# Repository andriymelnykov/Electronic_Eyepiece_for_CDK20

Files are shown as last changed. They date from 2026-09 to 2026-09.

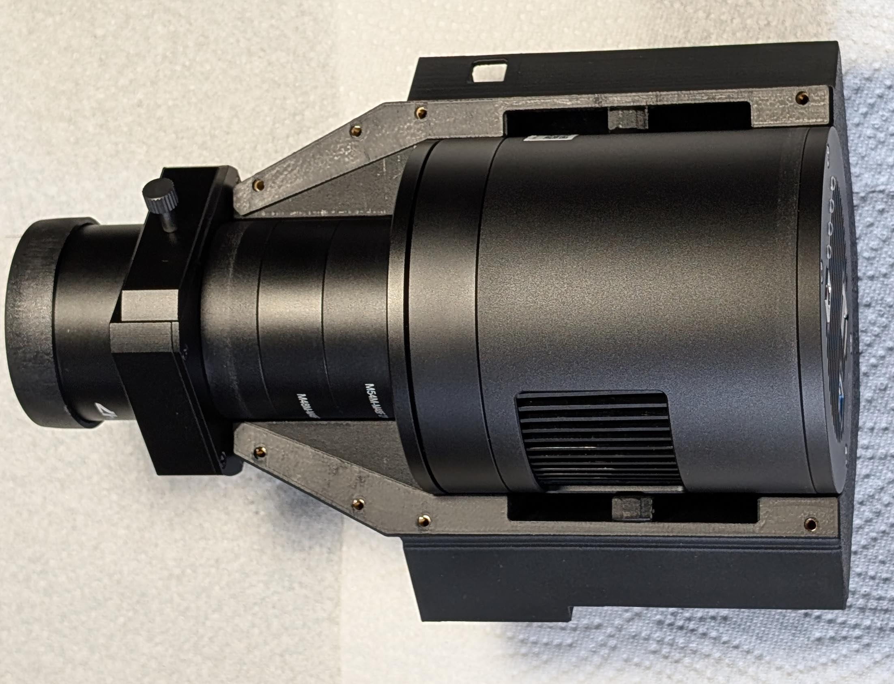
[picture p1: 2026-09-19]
Assembly/19_Assembly.jpg

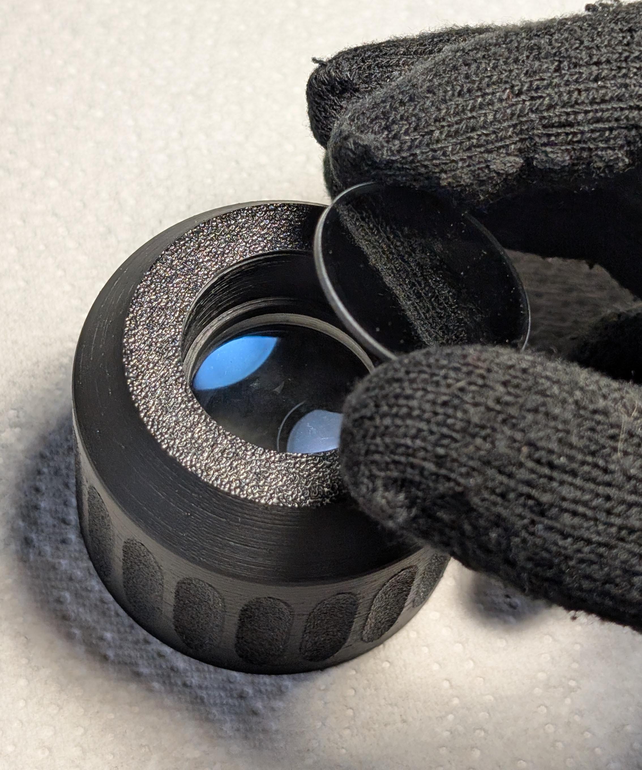
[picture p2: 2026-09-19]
Assembly/05_Assembly.jpg

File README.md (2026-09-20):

# Electronic_Eyepiece_for_CDK20
Electronic eyepiece for CDK20 telescope (or almost any 2-inch focuser)

This is my third creation of electronic eyepiece system for observing deep-sky objects.

The device was custom-developed and built for the Robert-Mayer-Sternwarte astronomy club in Heilbronn, Germany, with the main goal: to preserve the feeling of looking through a real telescope while making faint deep-sky objects such as galaxies and nebulae visible in color — even from the middle of the city.

The system combines the enormous light-gathering power of a 50 cm CDK20 telescope, a modern full-frame astronomy camera with an optical reducer, and electronic eyepiece display. Image processing is performed on an external PC using own custom-written, highly optimized, ultra-fast EAA (Electronically Assisted Astronomy) software.

Thanks to this combination, most objects begin to appear in the eyepiece almost immediately and develop into a detailed color image within well under a minute of live stacking.

The electronic eyepiece creates a very different observing experience compared with looking at a normal computer screen. The image is presented optically at infinity, similar to a conventional telescope eyepiece, so the object appears large, distant, and suspended in space. It gives the impression of actually looking into the telescope rather than watching an image on a monitor.

Although this version was designed specifically for our CDK20, the electronic eyepiece itself should work with many telescopes equipped with a 2-inch focuser and sufficient image-circle coverage for a full-frame sensor.

See it in action: https://youtu.be/fDfaFu6sCa4

See discussion here: https://www.cloudynights.com/forums/topic/1010946-my-third-eaa-setup-with-diy-electronic-eyepiece-for-local-astroclub

-------------------------
Software used on PC for image processing is my other project:
https://github.com/andriymelnykov/Digital_Eyepiece_APP

Config files are provided as used on our CDK20 telescope and are examples.
Proper dark frames and flat frames calibration and eventually fine tuning of parameters needed for each device and telescope combination.
Calibration frames must be updated periodically (capture with third party SW).
The relative position of optical unit to telescope should be maintained for proper flat correction (see alignment marks in user manual).

User manual is an example.

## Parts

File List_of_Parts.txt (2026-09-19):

1. Camera: ToupTek SkyEye24AC.
https://www.touptek-astro.com/dso-cooled-cameras/SkyEye24AC/

2. ToupTek M54M-M48F 21mm and M48M-M48F 16.5mm Extension Tubes from SkyEye24AC Package Contents.

3. TS-Optics TSVF215 M48M-M48F 15mm Extension Tube.
https://www.teleskop-express.de/de/adapter-10/adapter-verlaengerung-124/ts-optics-15mm-verlaengerung-mit-m48-2-filtergewinde-und-2-durchmesser-1651
Alternatively any M48M-M48F 15mm Extension Tube with outer diameter of 50.8 mm (2 inches).

4. TS-Optics TSFSLM48 M48 Filter Changer - strengthened Design.
https://www.teleskop-express.de/en/filters-254/filter-wheels-and-filterslider-120/ts-optics-m48-filter-changer-strengthened-design-10475
Plus filter holders, 3x in total.
Alternatively any M48M-M48F 2-inch filter holder with thickness of 16-18mm.

5. Optolong UV/IR Blocking Filter and Luminance Filter 2" mounted.
https://www.teleskop-express.de/en/filters-254/photo-r-g-b-and-ir-cut-filters-267/optolong-uv-ir-blocking-filter-and-luminance-filter-2-mounted-11845

6. Optolong 2" L-eNhance Nebula Filter.
https://www.teleskop-express.de/en/filters-254/photo-swanband-nebular-filters-304/photo-narrowband-filters-2-inch-m48-302/optolong-2-l-enhance-nebula-filter-for-dslr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

7. Baader 2" UHC-L Ultra-L-Booster Nebula Filter.
https://www.teleskop-express.de/en/filters-254/nebular-filters-for-visual-observing-88/baader-2-uhc-l-ultra-l-booster-nebula-filter-for-astrophotography-16364

8. TS-Optics CCD47 2" CCD Reducer 0.67x.
https://www.teleskop-express.de/en/astrophotography-and-photography-15/imaging-correctors-for-telescopes-138/ts-optics-2-ccd-reducer-0-67x-for-rc-flatfield-telescope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
Alternatively Astro Physics CCDT67 0.67x Focal Reducer should be ok, but not tested.

9. 2x compression springs 35mm x 9mm x 0.7mm from common spring set.
Depending on your preferences other springs may be needed.

10. Wisecoco 2.9 Inch 2K TFT LCD Display 2160x2160 LS029B3SX06 with HDMI control board.
https://de.aliexpress.com/item/1005008080918162.html

11. Fischerelektronik USB 2 B 180 - USB 2.0 Typ B connector receptacle.
https://www.reichelt.de/de/de/shop/produkt/usb_2_0_typ_b_buchse-304025
Or similar with same dimensions.

12. CHERRY MX1B-52NA Low profile RGB speed switch for keyboards.
https://www.reichelt.de/de/de/shop/produkt/cherry_mx_low_profile_silver_rgb_speed_-_tastenmodul-281332

13. Arduino Pro-Micro, ATMega32U4, 5V / 16 MHz.
https://www.reichelt.de/de/de/shop/produkt/arduino_kompatibles_micro_pro_board_atmega32u4_microusb-330660

14. RGB strip with 7x WS2812 LEDs.

15. Short microUSB cable.

16. 2x 561.OA61 OptiMedia Achromat OA61, Ø 31 mm, f = 135.5 mm.
https://astromedia.de/OptiMedia-Achromat-OA61
Alternatively achromats with same data.

17. Grey ND8 filter size 37mm.
https://www.ebay.de/itm/324441899850?var=513510410016
Glass diameter 33.0-33.2 mm.

18. Thick silicone grease.

19. Screws M3x8 - 3x

20. Screws M3x10 - 19x

21. Screws M3x16 - 6x

22. Screws M2.5x12 - 4x

23. Black 3d-printing filament.

24. Transparent 3d-printing filament.

25. M3 inserts for 3d-printing - 10x

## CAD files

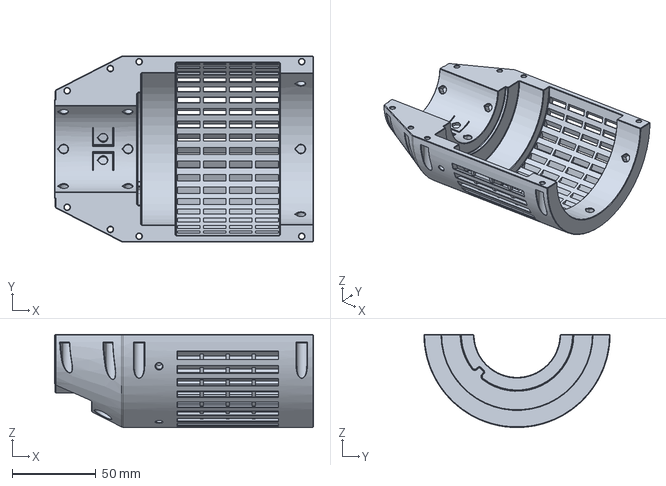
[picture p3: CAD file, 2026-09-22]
3D_Models/Case_Bottom.step
154.3 x 111.0 x 55.5 mm

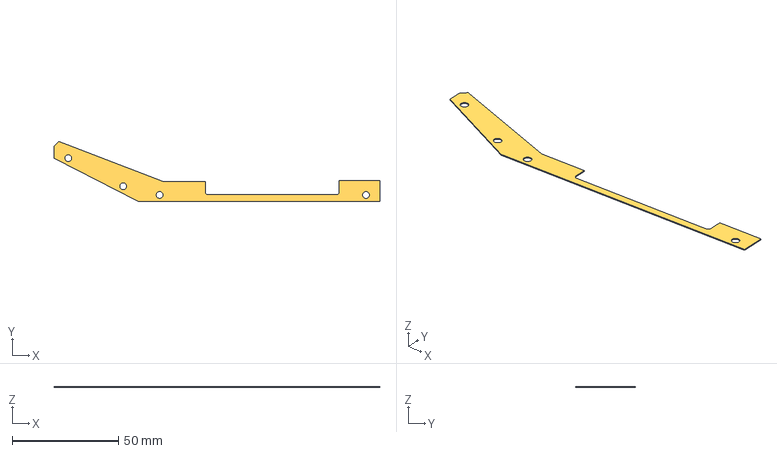
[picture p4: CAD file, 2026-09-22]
3D_Models/Gasket_Pad.step
153.1 x 28.2 x 0.4 mm

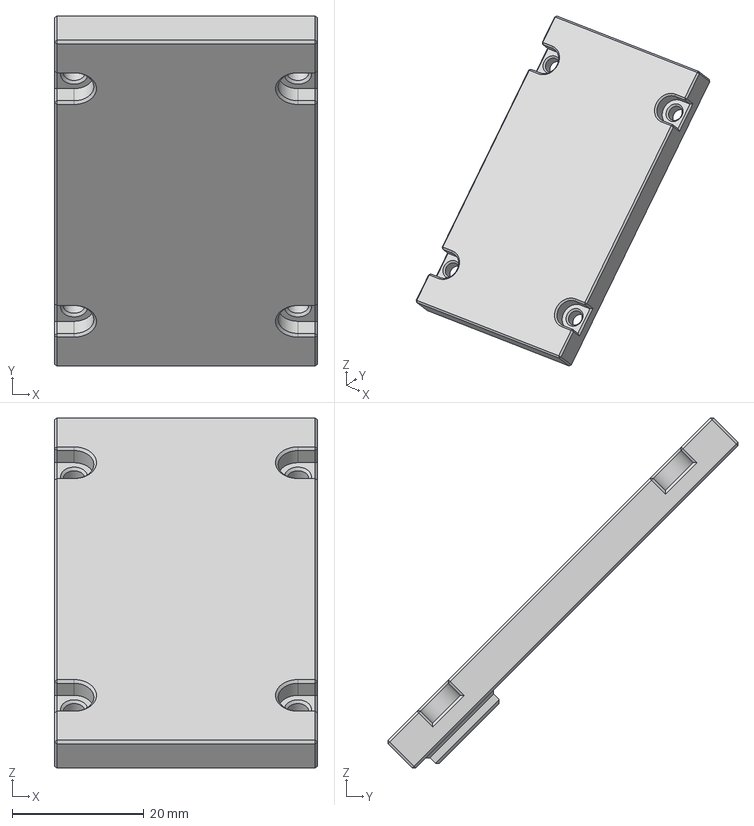
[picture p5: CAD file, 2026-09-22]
3D_Models/USB_Cover.step
40.0 x 53.2 x 53.2 mm

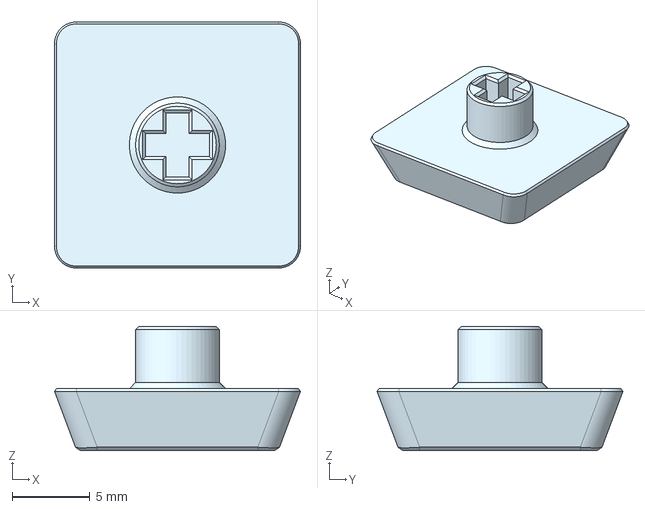
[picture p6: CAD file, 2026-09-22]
3D_Models/alternative_Keycap_1color.step
15.9 x 15.9 x 8.00 mm

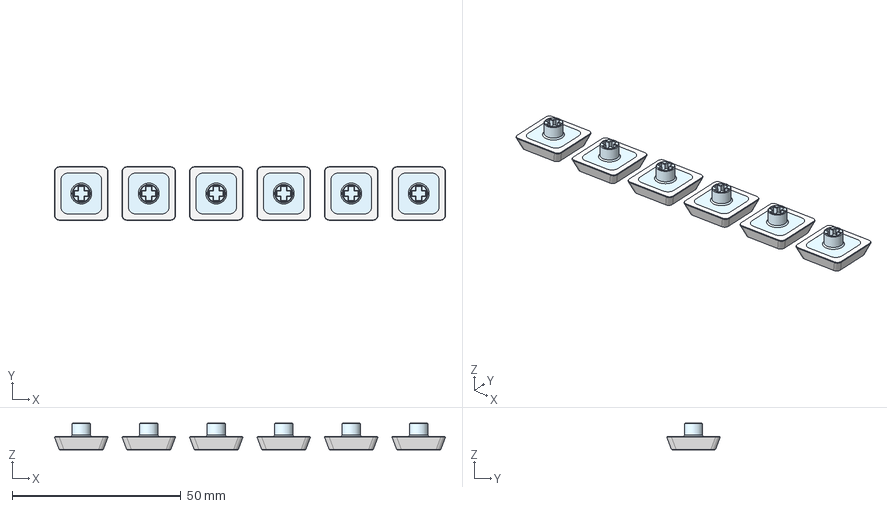
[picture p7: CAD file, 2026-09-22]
3D_Models/Keycaps_2color.step
115.9 x 15.9 x 8.00 mm

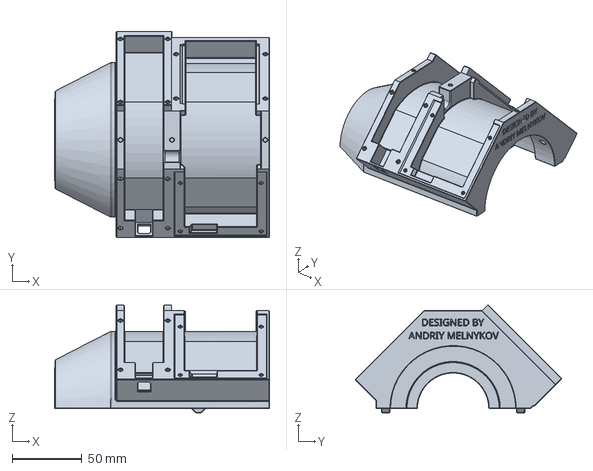
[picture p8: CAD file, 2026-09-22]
3D_Models/Case_Top.step
154.3 x 147.9 x 77.3 mm

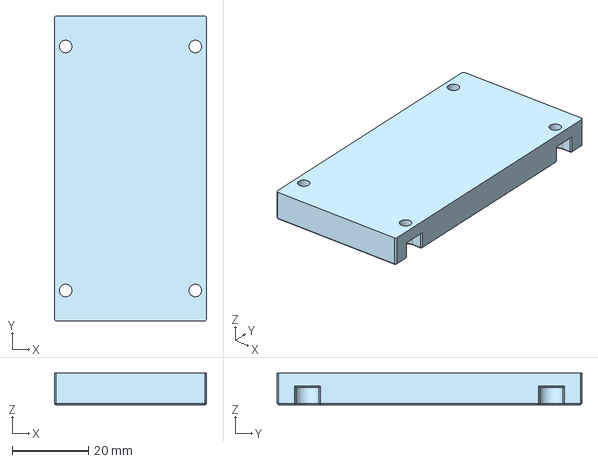
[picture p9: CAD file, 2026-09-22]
3D_Models/alternative_Keyboard_Part1.step
40.0 x 80.0 x 8.30 mm

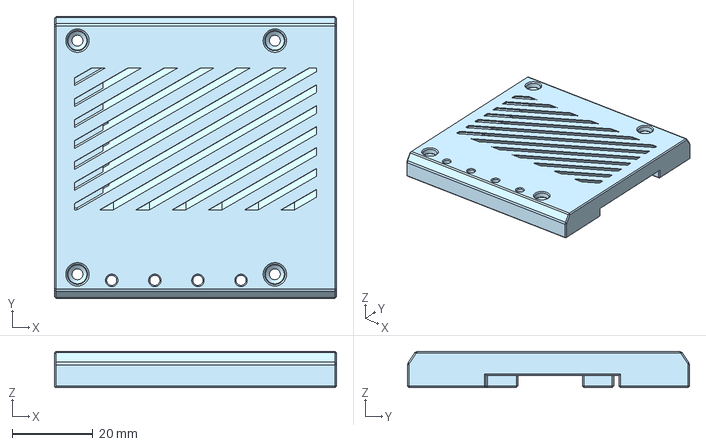
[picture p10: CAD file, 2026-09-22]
3D_Models/alternative_Cover_HDMI.step
70.0 x 70.0 x 9.00 mm

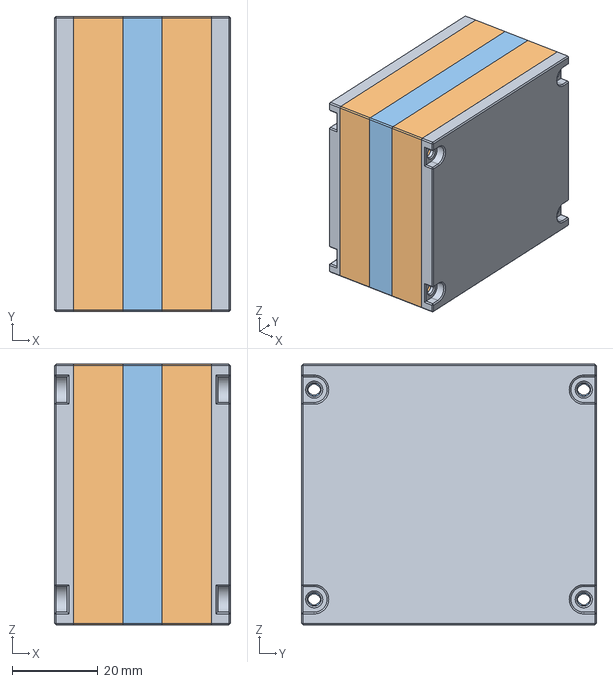
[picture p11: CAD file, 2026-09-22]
3D_Models/Filterbox_multipart.step
41.2 x 69.0 x 61.0 mm

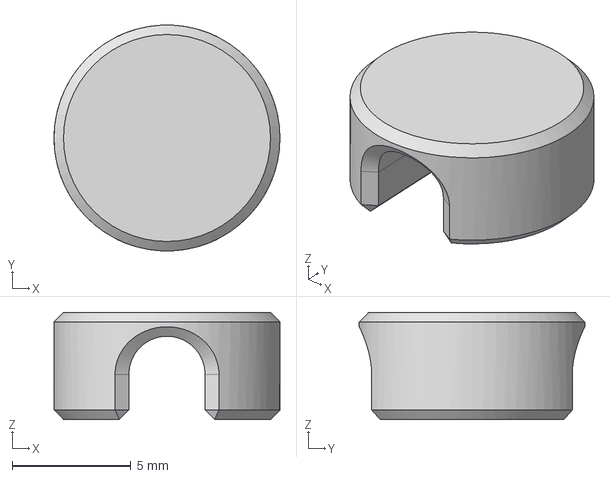
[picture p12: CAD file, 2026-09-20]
3D_Models/Stopper.step
9.50 x 9.50 x 4.50 mm

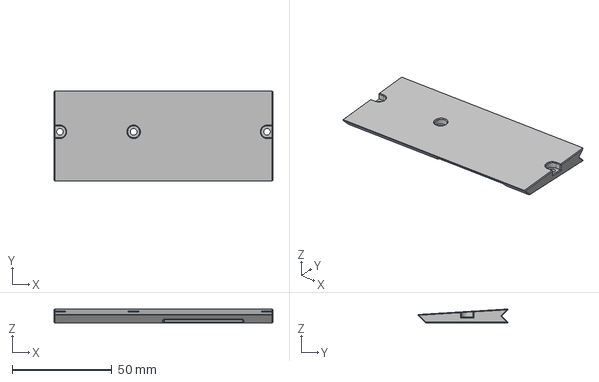
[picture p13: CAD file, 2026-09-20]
3D_Models/Front_Cover.step
110.0 x 45.4 x 7.05 mm

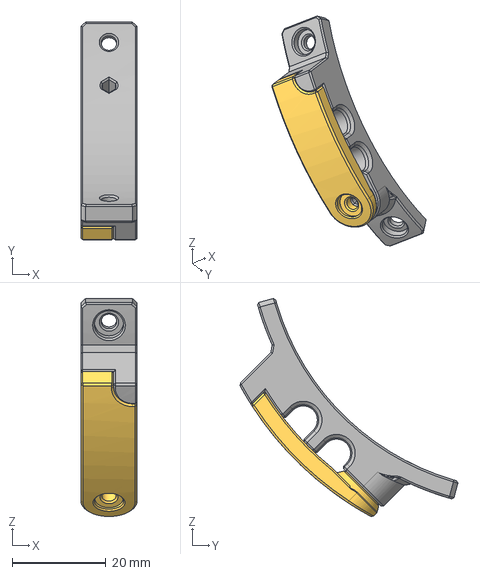
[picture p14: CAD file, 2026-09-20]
3D_Models/Cable_Holder.step
12.0 x 46.4 x 46.4 mm

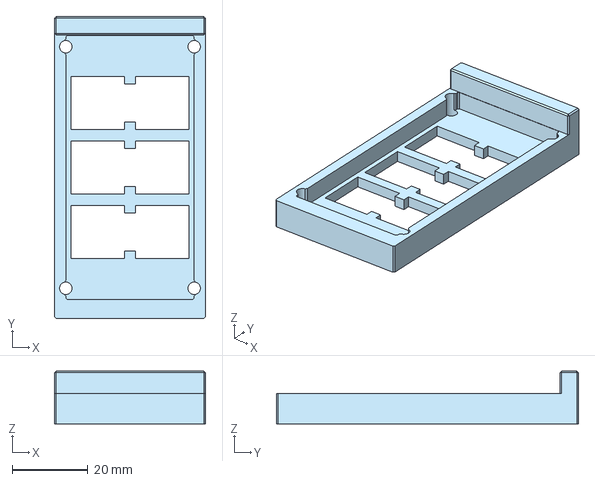
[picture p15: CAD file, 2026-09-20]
3D_Models/Keyboard_Part2.step
40.0 x 80.0 x 14.0 mm

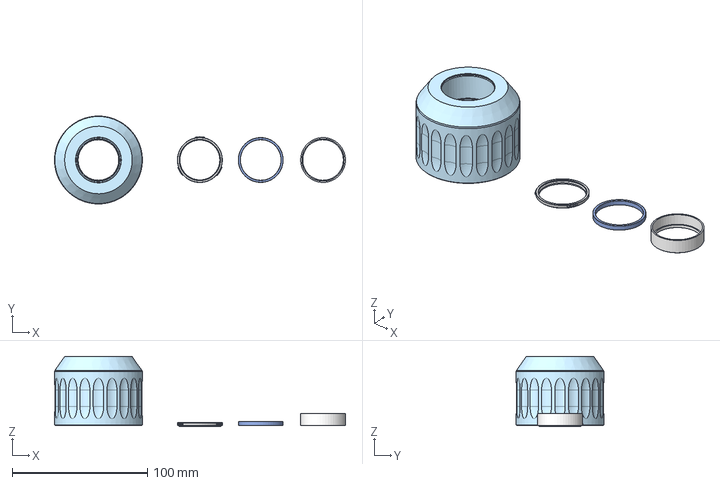
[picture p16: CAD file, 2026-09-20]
3D_Models/Lens_Holder_and_Rings_Layer0_1_RandomSeam.step
215.2 x 65.0 x 51.8 mm

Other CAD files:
3D_Models/Cover_HDMI.step
3D_Models/Eyepiece_Body_Layer0_1_RandomSeam.step
3D_Models/Keyboard_Part1.step
3D_Models/Eyepiece_Cap_TPU.step

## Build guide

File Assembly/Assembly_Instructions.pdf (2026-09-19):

Assembly instructions for: Electronic_Eyepiece_for_CDK20
19.09.2026
Andriy Melnykov

The electronic eyepiece assembly comprises an astronomical camera, extension tubes, filter changer, optical reducer (which also functions as a 2-inch insertion barrel), display module, and keypad.
The camera, extension tubes, optical reducer, and filter changer are integrated into a permanently assembled optical unit. The outer housing, which incorporates the display and keypad, is mounted on a rotatable support and can be rotated around the camera body to provide a convenient viewing and operating position.

Paint relevant surfaces near display with black matte paint:

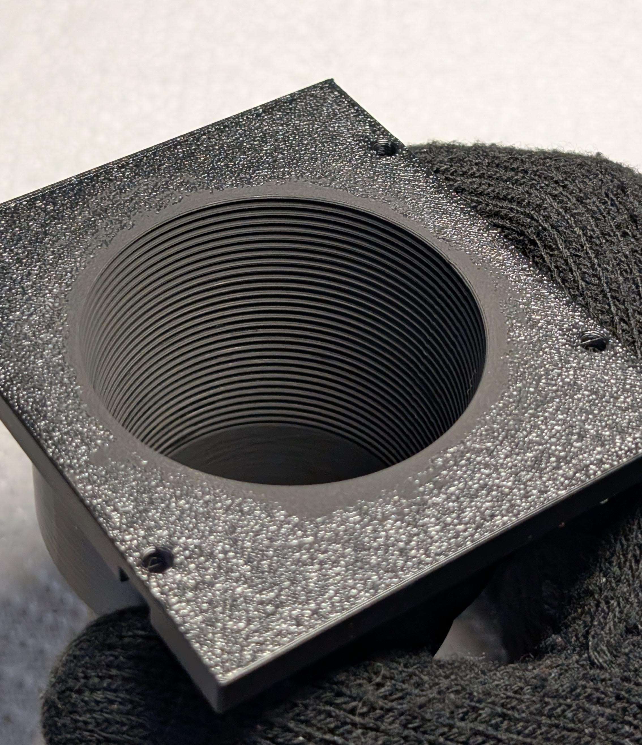
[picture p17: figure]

Insert first lens, pay attention to the lens orientation:

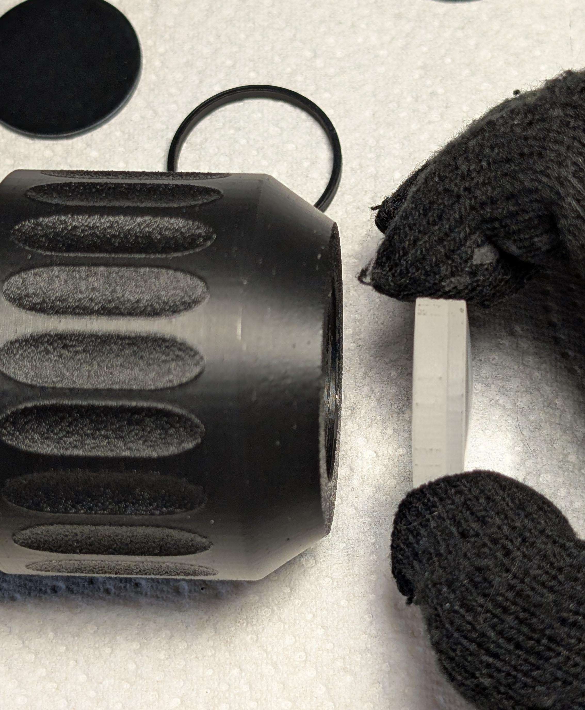
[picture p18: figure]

Insert spacer ring:

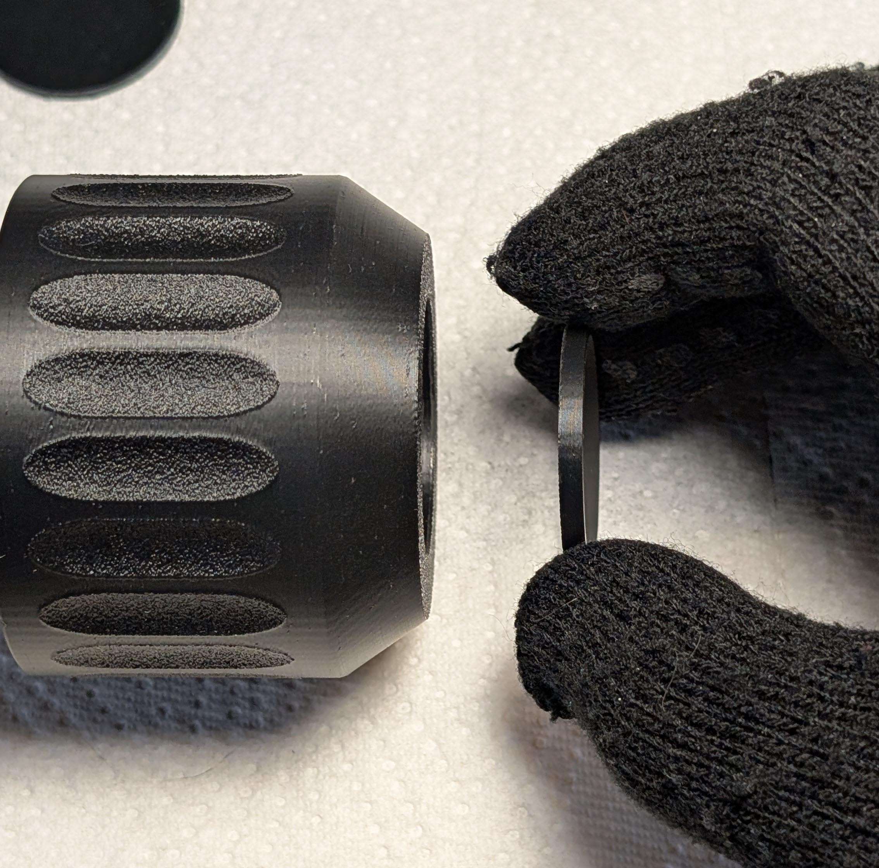
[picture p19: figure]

Insert grey ND filter:

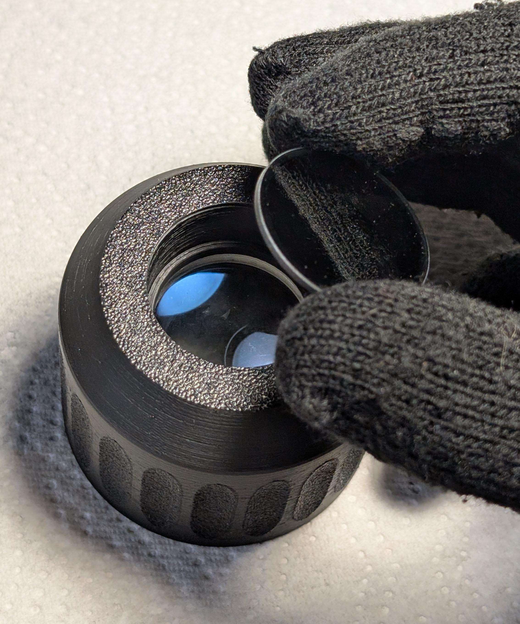
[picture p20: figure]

Insert second lens spacer-holder, pay attention to the orientation:

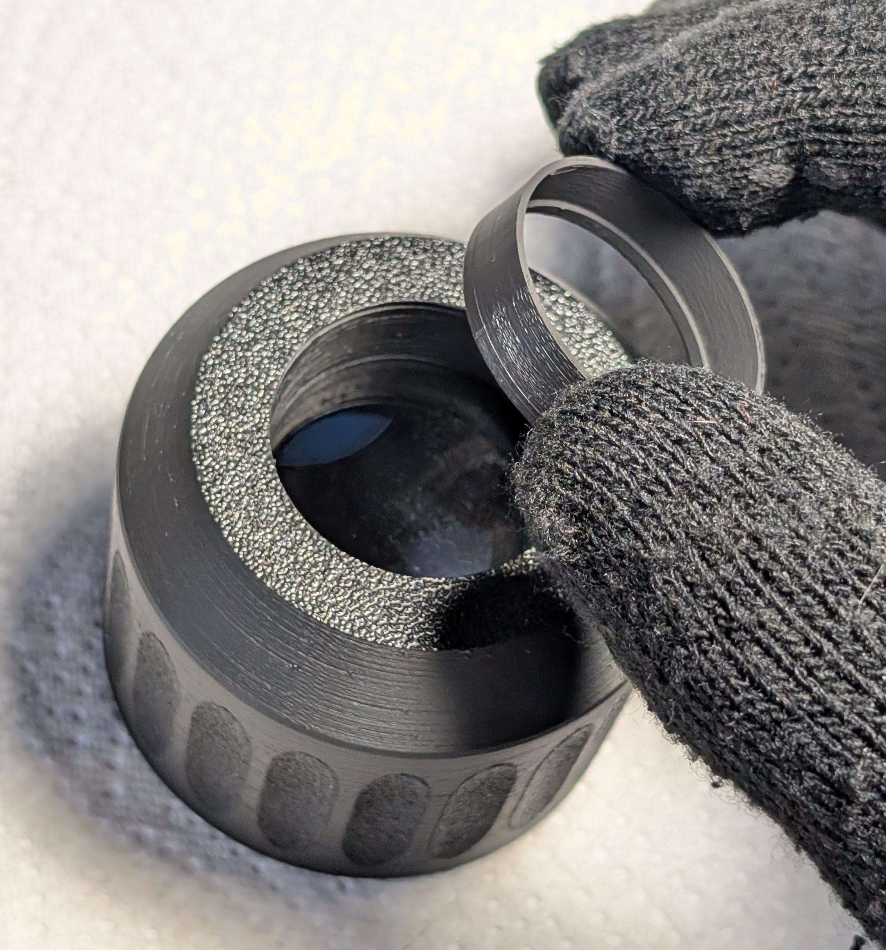
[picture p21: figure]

Insert second lens, pay attention to the lens orientation:

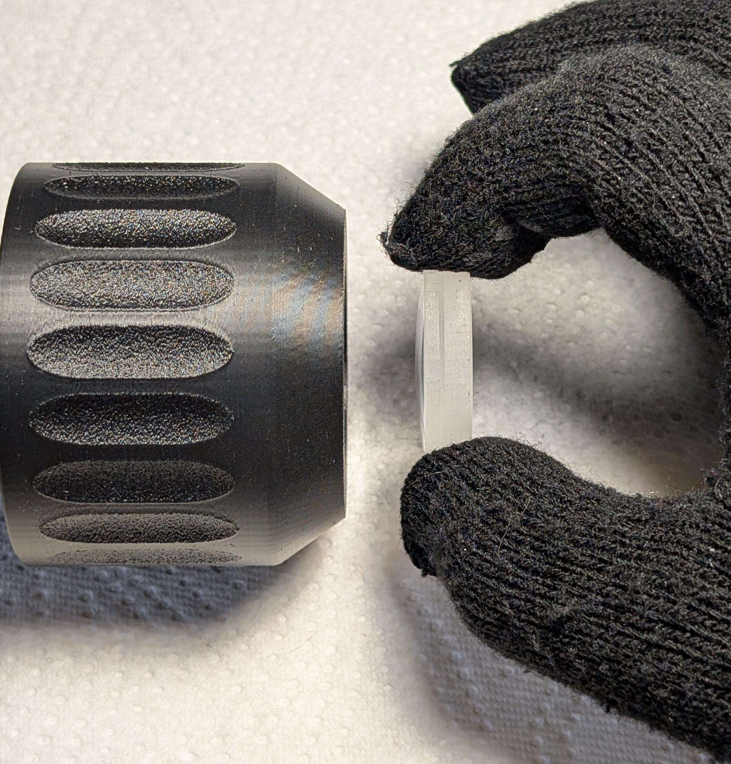
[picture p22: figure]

Press in fixation ring, pay attention to the ring orientation:

Place silicone grease on the thread carefully:

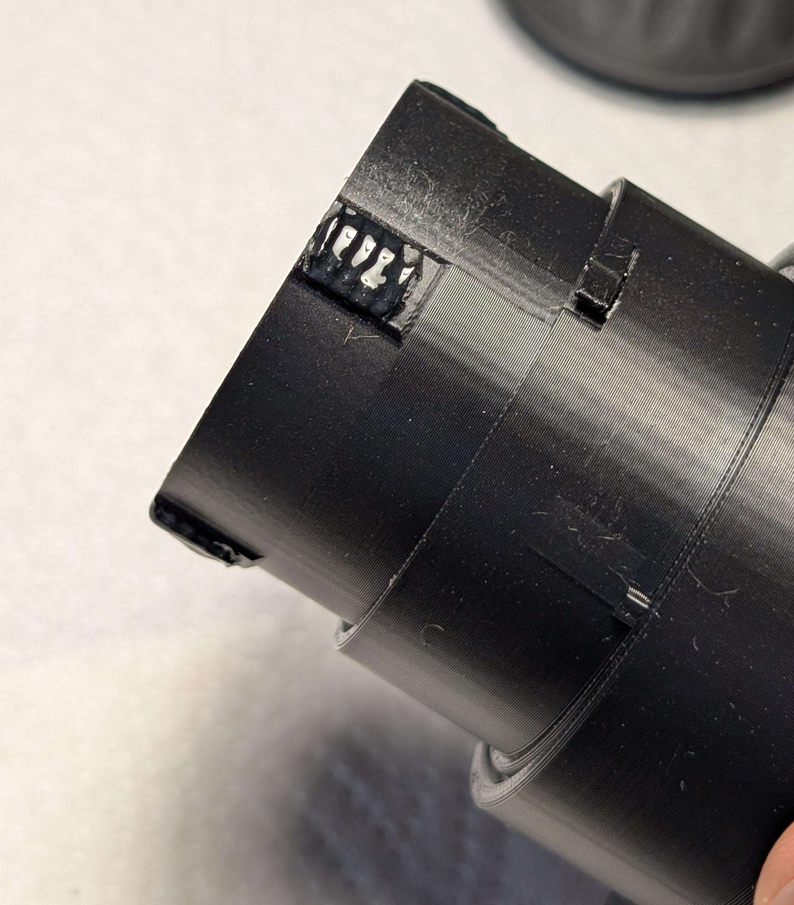
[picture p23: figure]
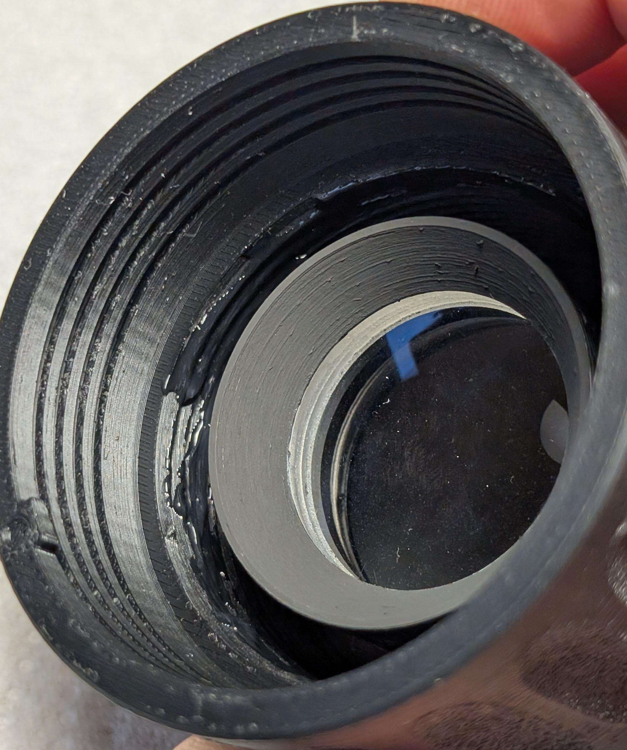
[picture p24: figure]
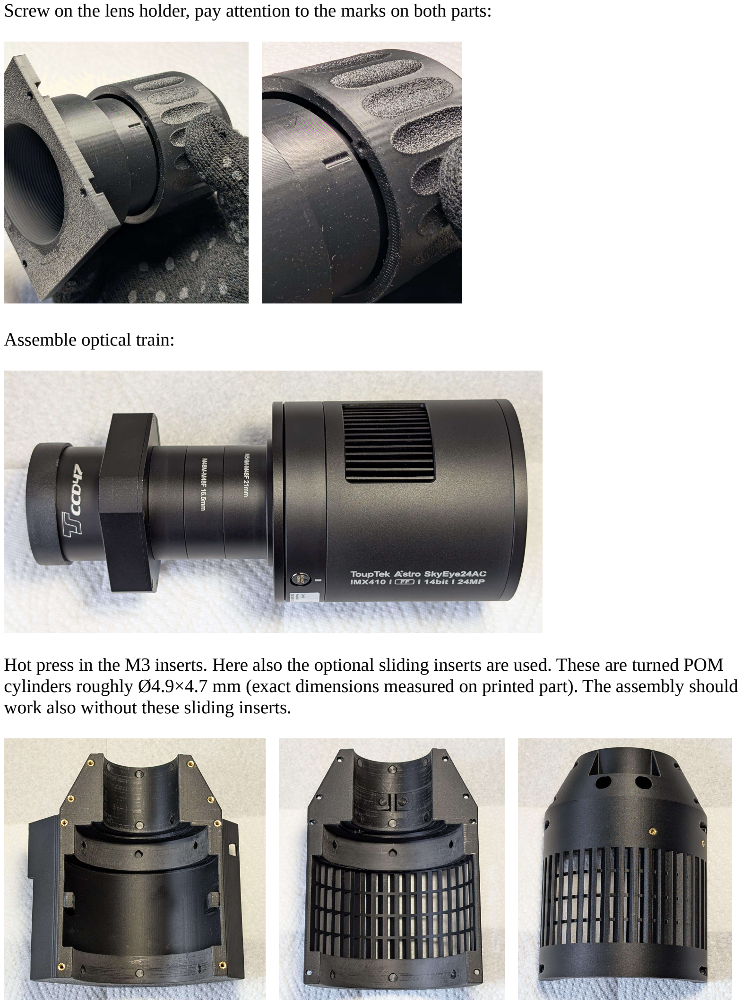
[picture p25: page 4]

Screw on the lens holder, pay attention to the marks on both parts:

Assemble optical train:

Hot press in the M3 inserts. Here also the optional sliding inserts are used. These are turned POM cylinders roughly Ø4.9×4.7 mm (exact dimensions measured on printed part). The assembly should work also without these sliding inserts.

Other holes in plastic (M3 and M2.5) are meant to be tapped with corresponding threads. Hower, the geometry of holes allows to simply force screws in – less convenient and safe, but should also work.

This screw (from package content of the camera) is used as a rotational stop:

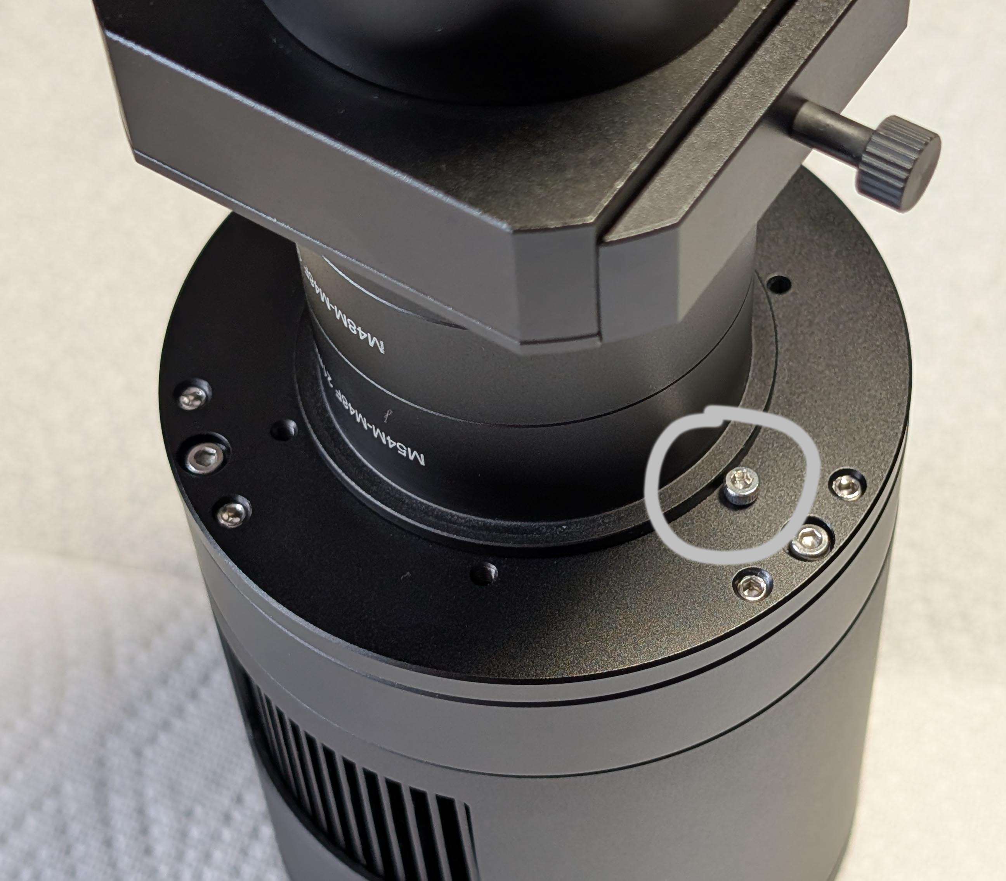
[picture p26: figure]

Place assembled optical train in the half of outer housing:

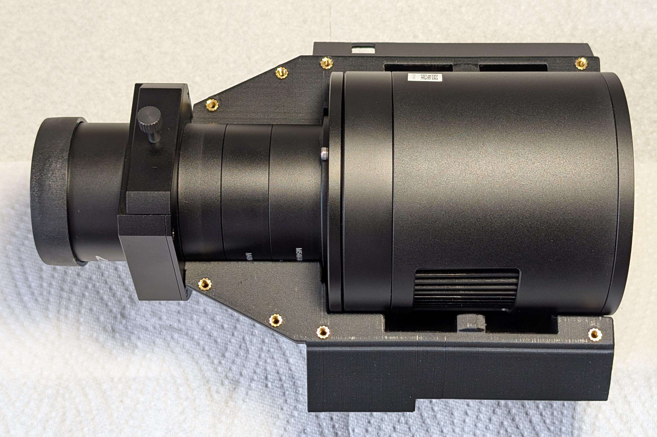
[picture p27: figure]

Here additional pad spacers between housing halves are used to adjust free rotation of the housing around the camera:

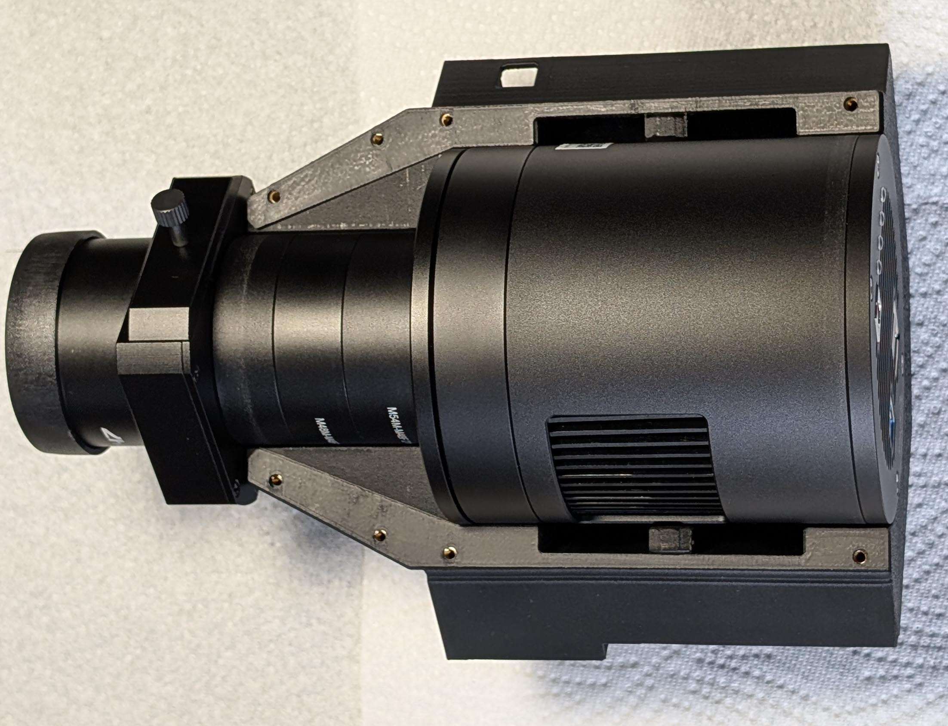
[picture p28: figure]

Close the second half of the housing and fixate with M3x10 screws. Check for free rotation:

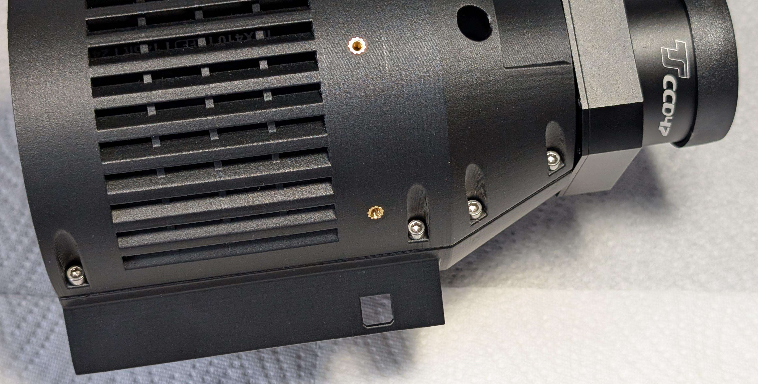
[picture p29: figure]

Place the springs over friction pads, and, together with stoppers, press them in, then fixate with M3x16 screws. BE CAREFUL!
Depending on personal preference (how much friction you need during rotation) you can change the springs or e.g. install two springs with different diameter for each friction pad.

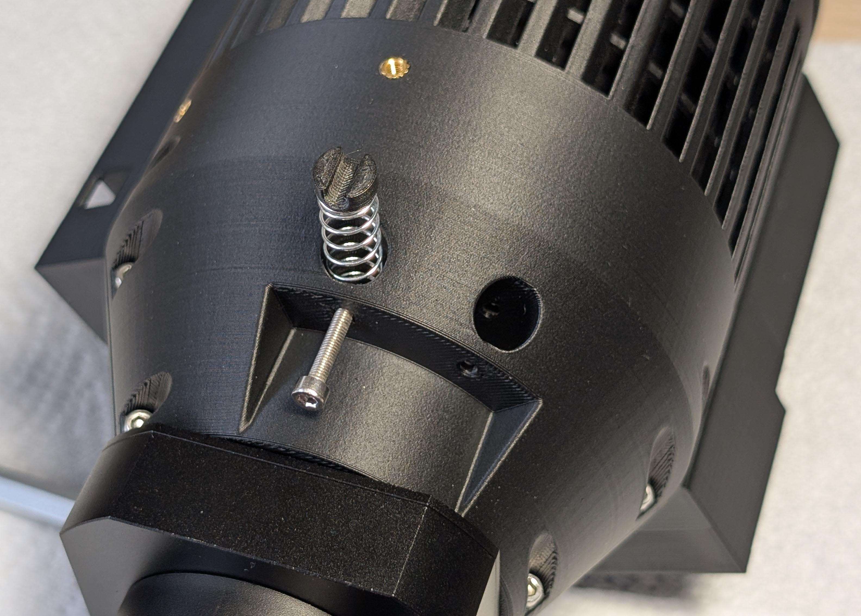
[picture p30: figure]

Solder power wires to the display HDMI board. These cables are soldered to USB-B receptacle connector together with short piece of microUSB cable in parallel (pinning according to USB standard):

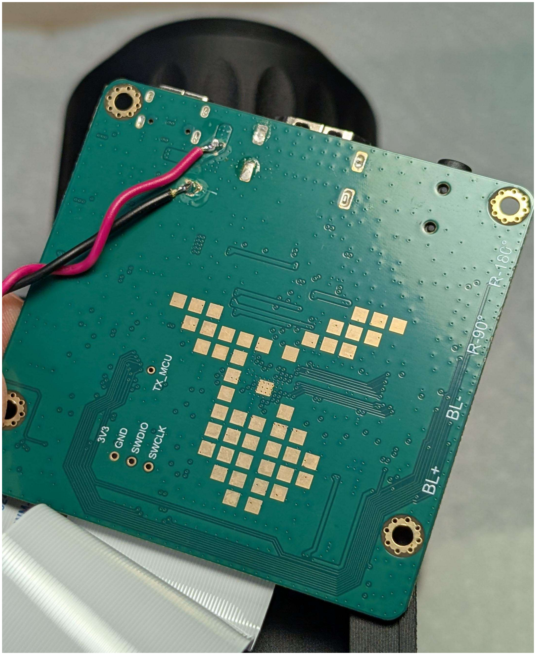
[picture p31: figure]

Place display screen with flat cable underneath (folded), and fixate the lens assembly over it with M3x10 screws:

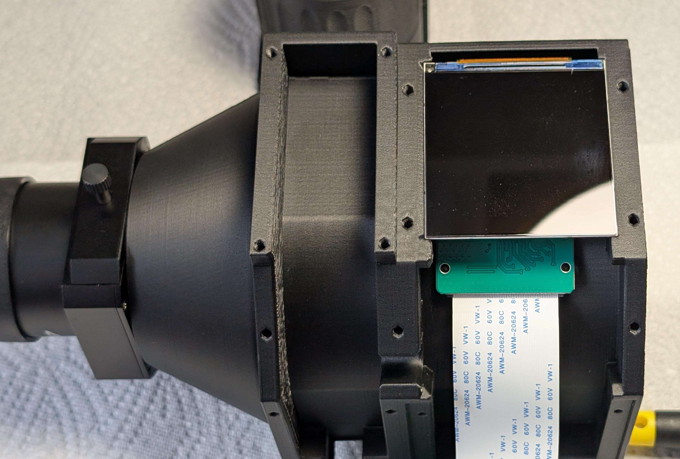
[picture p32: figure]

Place a peace of foam under the screen to isolate it from the PCB on the flat cable. Place flat cable under the HDMI controller PCB (folded):

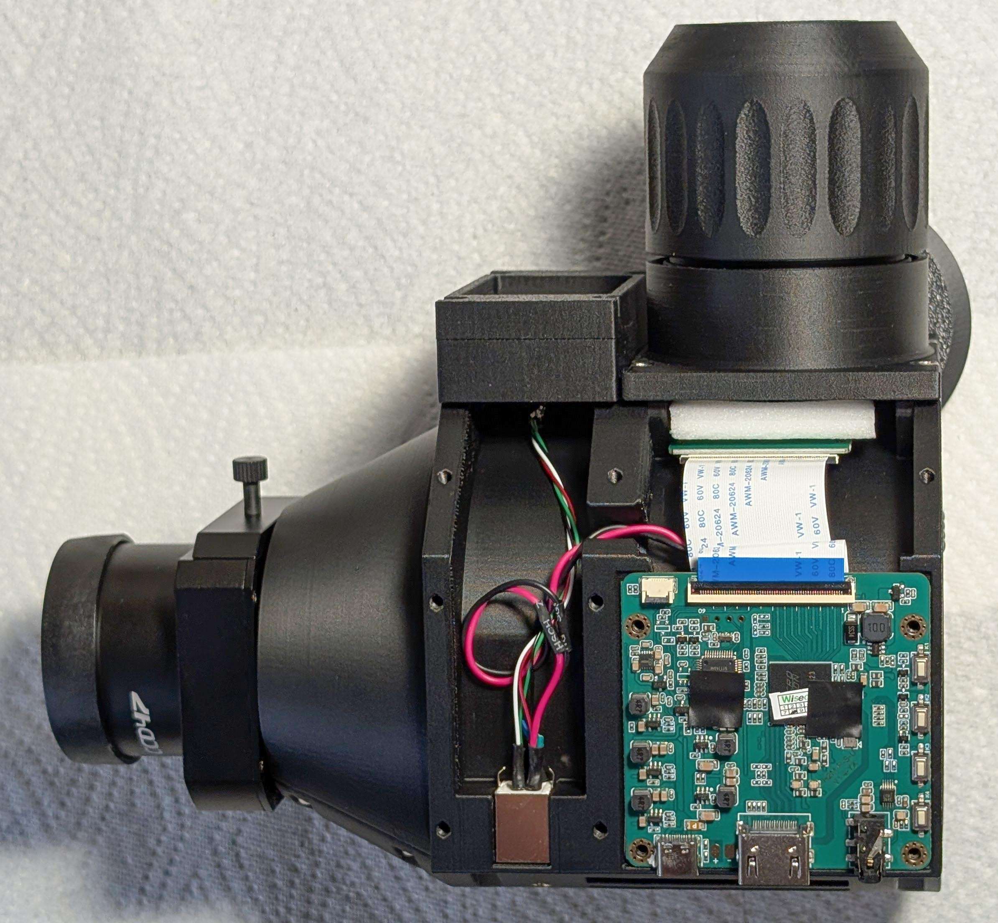
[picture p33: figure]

Fixate the HDMI controller PCB with M2.5x12 screws, and USB-B connector with cover panel and M3x10 screws:

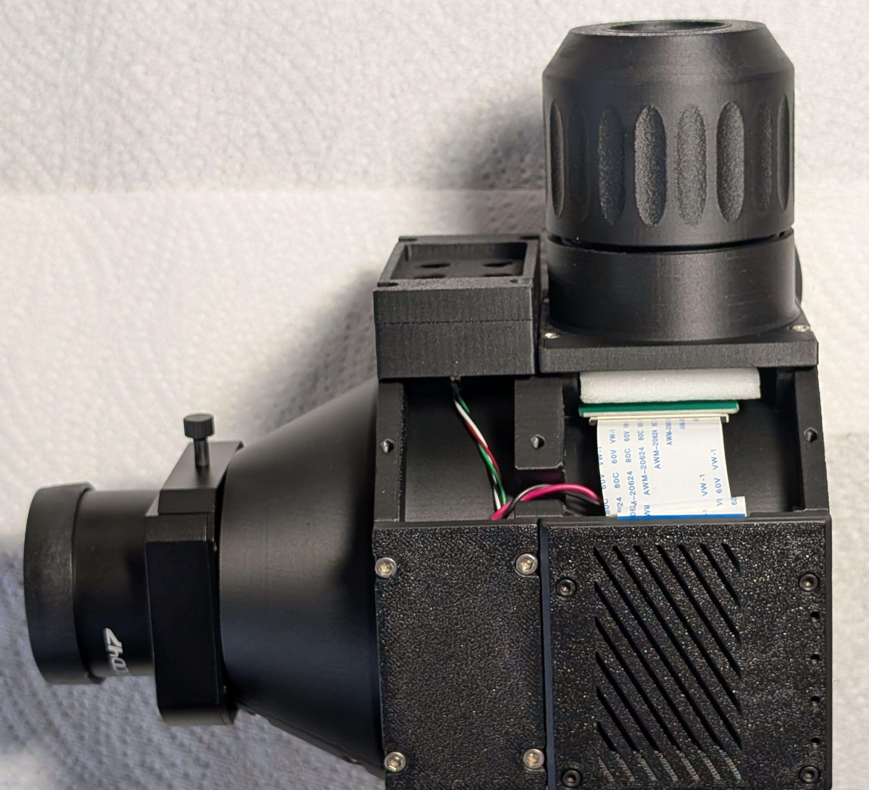
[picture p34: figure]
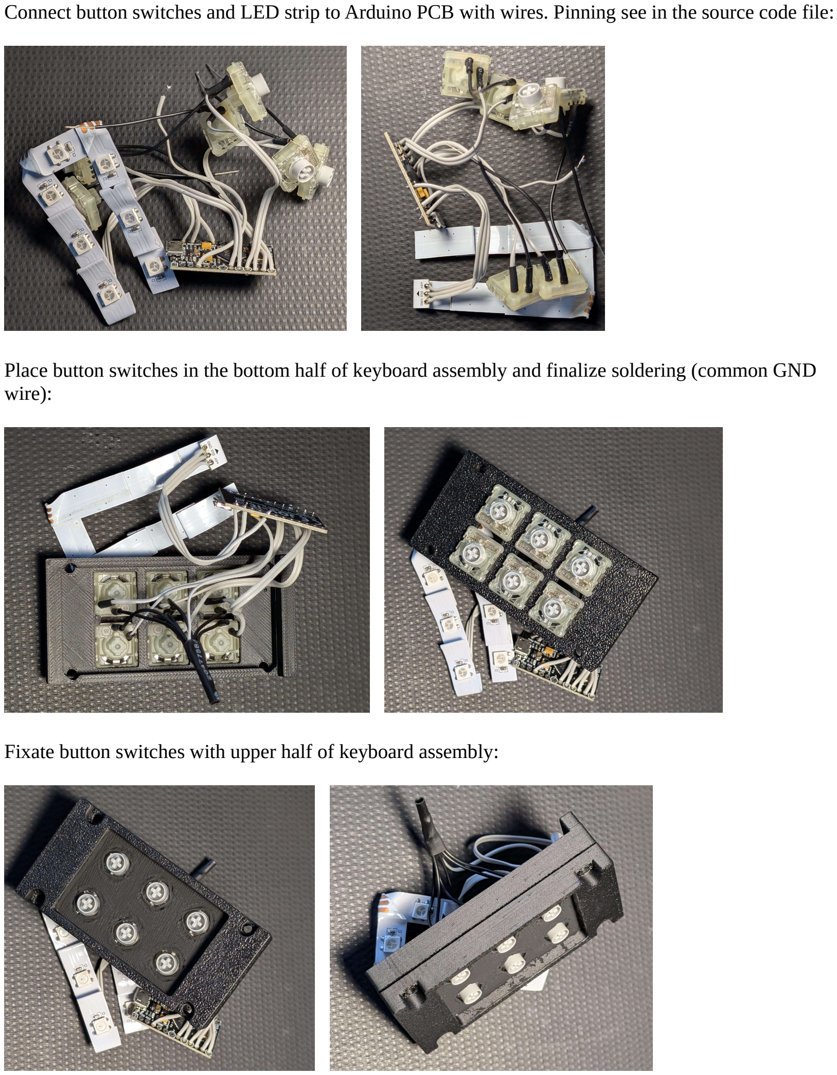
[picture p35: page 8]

Connect button switches and LED strip to Arduino PCB with wires. Pinning see in the source code file:

Place button switches in the bottom half of keyboard assembly and finalize soldering (common GND wire):

Fixate button switches with upper half of keyboard assembly:

Fixate LED strip with hot glue or similar. Pay attention to screw holes:

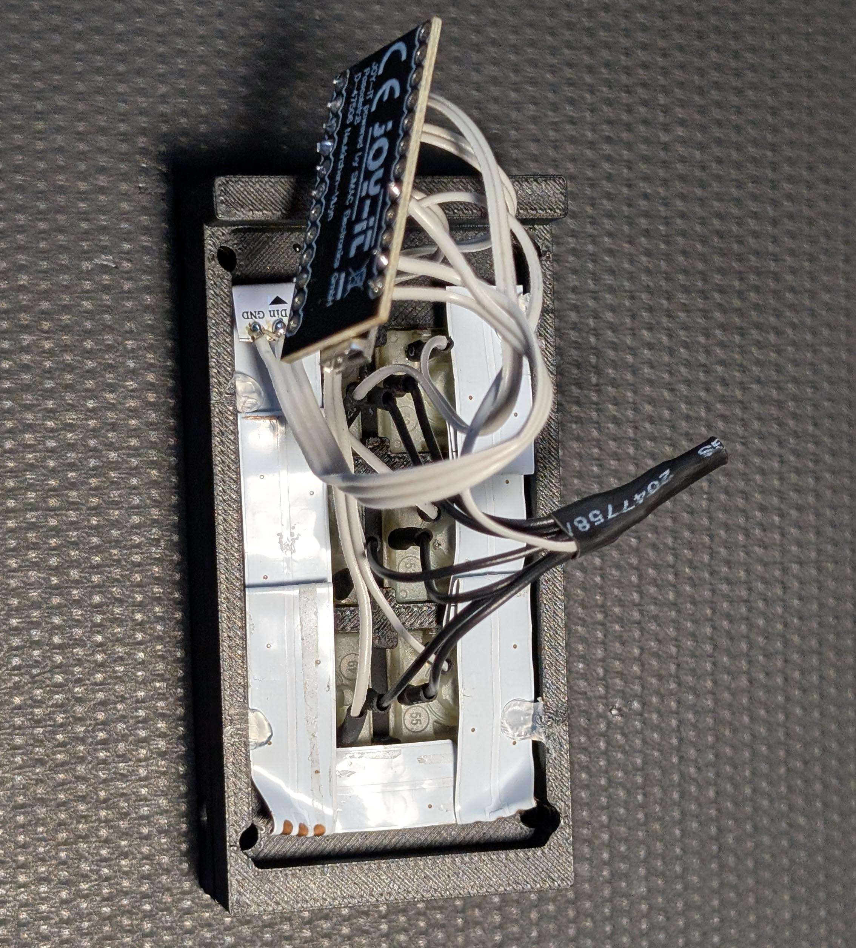
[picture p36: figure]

Fixate keyboard assembly on the housing with M3x16 screws, connect microUSB cable to Arduino:

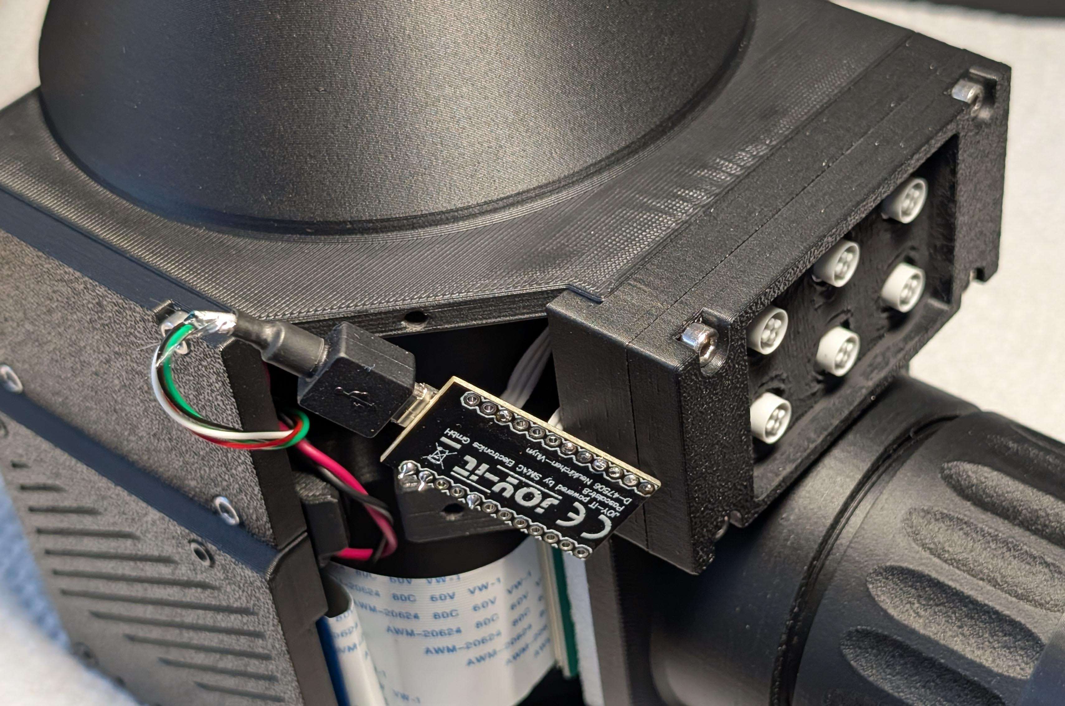
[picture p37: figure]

Close the last housing cover with M3x10 screws:

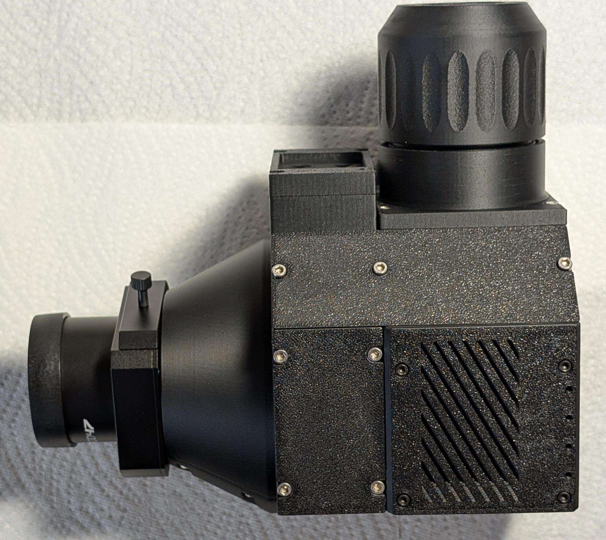
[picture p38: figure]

Install (press in) the key caps:

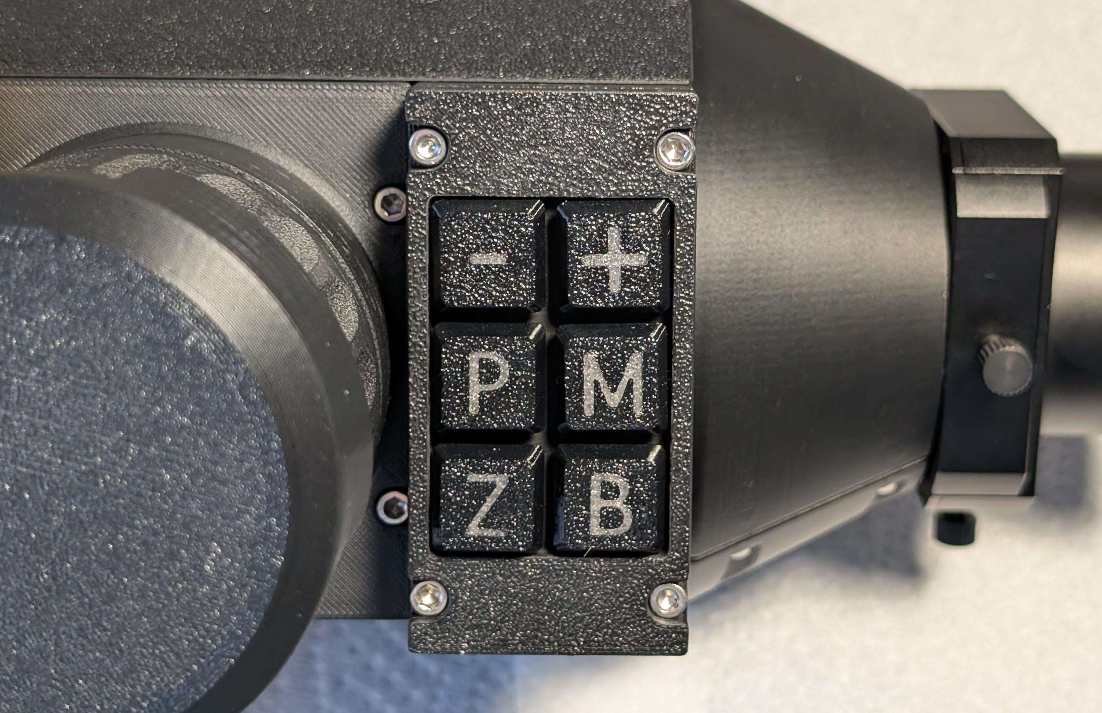
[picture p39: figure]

Assemble cable holder on the side of the housing with M3x8 screws:

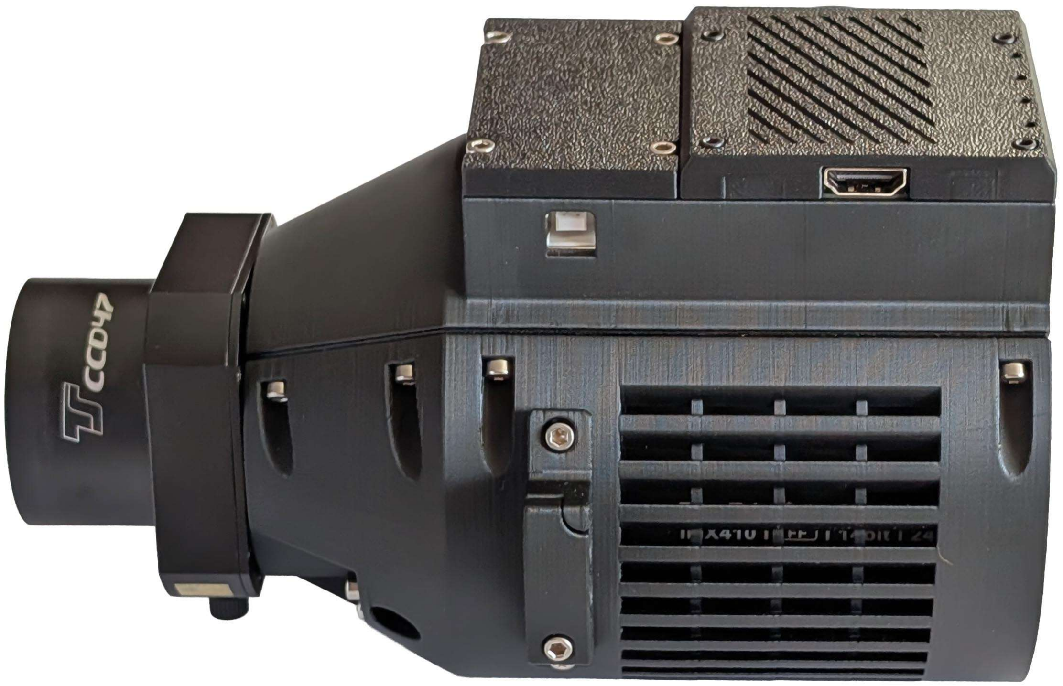
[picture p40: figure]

If you don’t want to use keyboard and USB-B connector, device can be assembled without them using two alternative covers. In this case power for display is connected over USB-C connector of display controller.

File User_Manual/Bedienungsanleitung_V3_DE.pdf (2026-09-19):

Anleitung für das elektronische Okular am CDK20, V3, 19.09.2026

Das elektronische Okular ist für die Beobachtung von Deep-Sky Objekten (Galaxien, Nebel, Kugelsternhaufen, Sterne) mit dem CDK20 Teleskop vorgesehen.
Das Okular ist nicht für den Mond oder Planeten geeignet und darf auf keinen Fall für die Sonne verwendet werden!
Das elektronische Okular besteht aus: Astrokamera, Filterschublade, optischem Reducer (dient gleichzeitig als 2-Zoll-Hülse), Okular-Display, Tastatur. Die Kamera, der Reducer und die Filterschublade bilden die fest montierte optische Einheit. Das äußere Gehäuse mit Display und Tastatur ist drehbar gelagert und kann zur bequemeren Beobachtung um die Kamera gedreht werden.

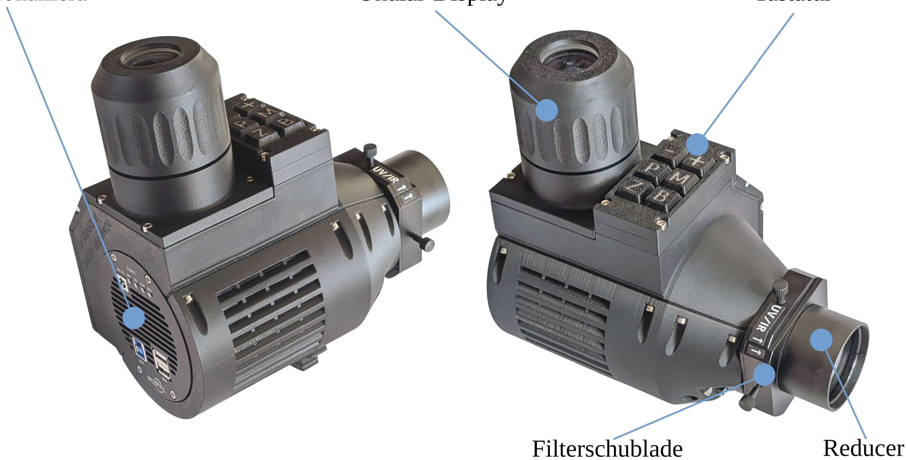
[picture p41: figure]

Montage

Das elektronische Okular wird direkt (ohne Zenitspiegel) in die 2-Zoll-Aufnahme des CDK eingesteckt und mit Rändelschrauben befestigt. Dabei ist Folgendes zu beachten:
- Die hellen Markierungen am Okular und am Teleskop müssen übereinstimmen.
- Außerdem ist zu prüfen, ob die zwei kleinen Markierungen am CDK übereinstimmen.
- Das Okular muss bündig und ohne Verkippung befestigt werden.
Astrokamera | Okular-Display | Tastatur

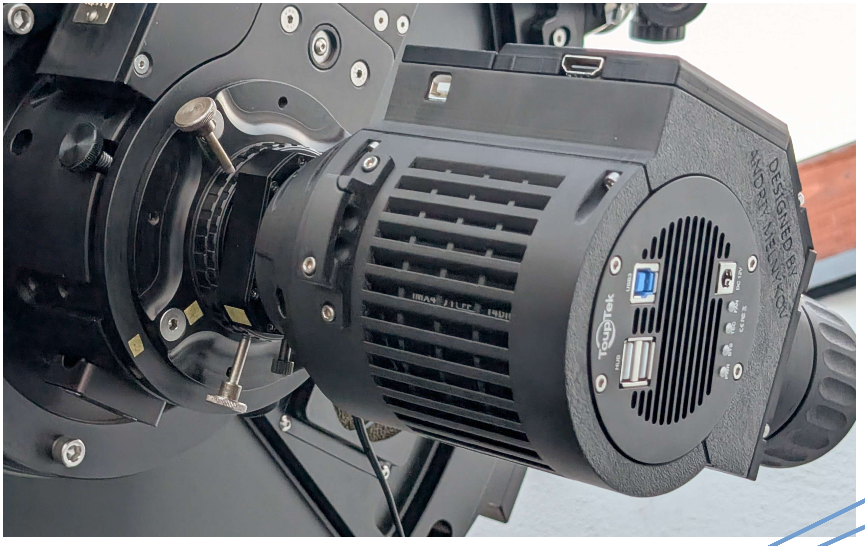
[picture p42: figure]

Markierungen

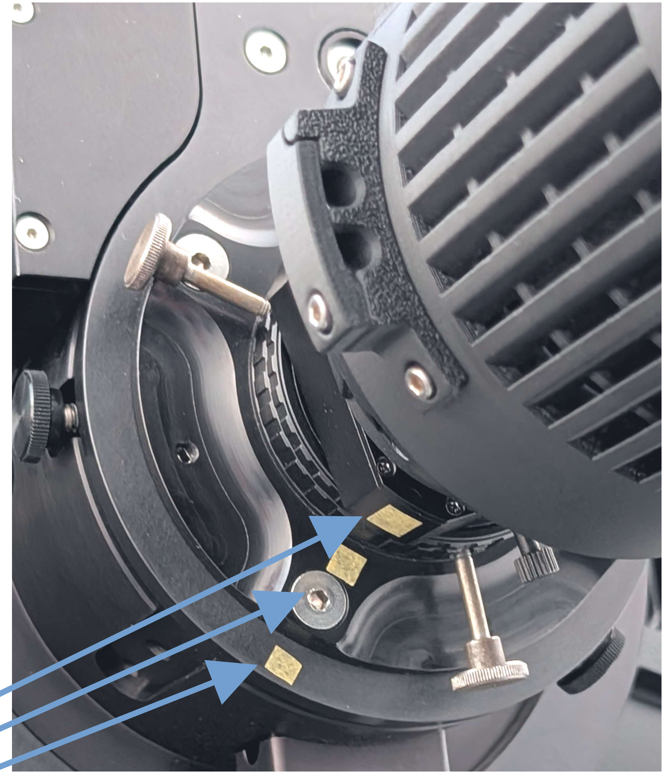
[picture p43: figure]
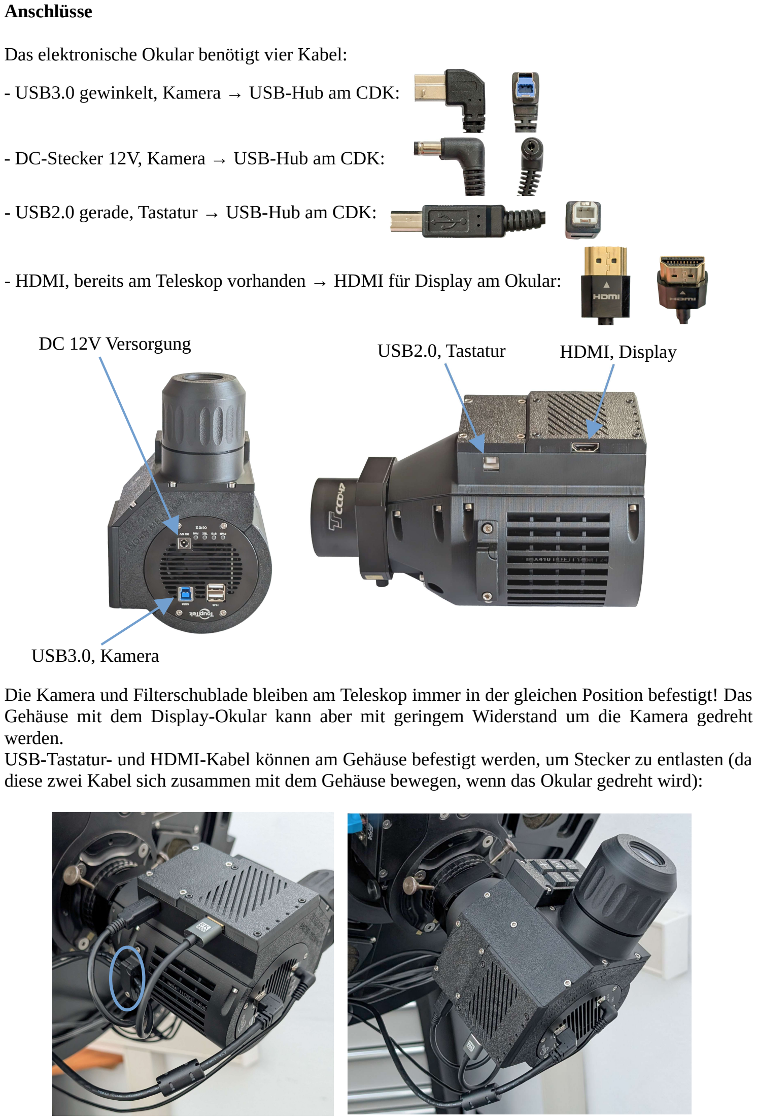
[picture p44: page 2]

Anschlüsse

Das elektronische Okular benötigt vier Kabel:

- USB2.0 gerade, Tastatur → USB-Hub am CDK:
- HDMI, bereits am Teleskop vorhanden → HDMI für Display am Okular:

Die Kamera und Filterschublade bleiben am Teleskop immer in der gleichen Position befestigt! Das Gehäuse mit dem Display-Okular kann aber mit geringem Widerstand um die Kamera gedreht werden.
USB-Tastatur- und HDMI-Kabel können am Gehäuse befestigt werden, um Stecker zu entlasten (da diese zwei Kabel sich zusammen mit dem Gehäuse bewegen, wenn das Okular gedreht wird):

USB2.0, Tastatur HDMI, Display

USB3.0, Kamera

DC 12V Versorgung

Bedienung

Die Software-App für das elektronische Okular befindet sich auf dem CDK-Rechner im Ordner „DigitalEyepieceAPP_CDK_V3“ auf dem Desktop. Im Ordner sind 3 Verknüpfungen zu finden, um die Software mit unterschiedlichen Einstellungen zu starten.
- „DigitalEyepieceAPP“ startet die Software im Standardmodus mit 0,5° Sichtfeld.
- „DigitalEyepieceAPP_ZOOM“ startet die Software im 2-fach-Zoommodus mit 0,25° Sichtfeld. Dieser Modus hat eine geringere Empfindlichkeit als der Standardmodus.
- „DigitalEyepieceAPP_HighSensitivity“ startet die Software im Modus mit 0,5° Sichtfeld, mit mehr Empfindlichkeit, weniger Auflösung und weniger aggressiven Farben – für sehr dunkle Objekte.
Die Software wird am PC mit wenigen Schaltflächen angesteuert oder alternativ mit der Tastatur am Okular. Die 6 Knöpfe am Okular entsprechen den 6 oberen Schaltflächen in der Software.
Bilder werden automatisch jede Minute gespeichert und befinden sich im Ordner „SW/saved_pictures“.
-, + | -, + | Helligkeit, Stretching, Details hervorheben
Palette change | P | Farbpaletten für Filter umschalten
Mode change | M | Echtzeit-/Stacking-Modus umschalten
Zoom | Z | Vergrößerung des Bildes
Background correction | B | zusätzliche Hintergrundkorrektur
Save picture | | Bild speichern
Exit | | Programm beenden

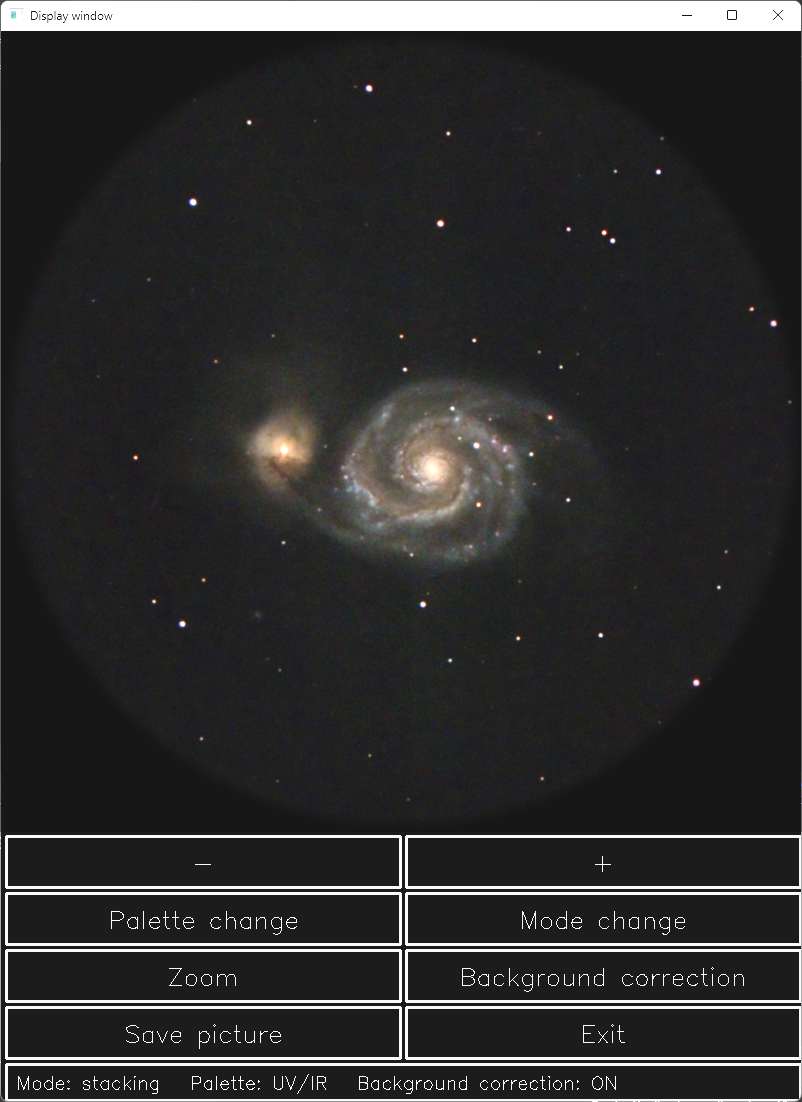
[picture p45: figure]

-, +: regeln die Helligkeit des Bildes und wie viele Details vom Deep-Sky-Objekt angezeigt werden. Es ist sinnvoll, diese Einstellung zunächst niedrig zu halten (um weniger Rauschen zu sehen) und im Laufe des Stackings höher einzustellen (um mehr Details zu sehen). Es gibt zu jeder Zeit einen Kompromiss zwischen Rauschen und Details.
Mode change, M: Umschalten zwischen Echtzeitmodus und Stacking-Modus. Im Echtzeitmodus kann man z. B. das Teleskop bewegen, um das Objekt zu zentrieren. Im Stacking-Modus soll das Teleskop ruhig bleiben und die Montierung soll im Nachführmodus laufen.
Zoom, Z: Aktivierung/Deaktivierung der digitalen Vergrößerung, manchmal sehen kleine Objekte so besser aus. Wird auch fürs Fokussieren im Echtzeitmodus benutzt. Alternativ kann die Software über die Verknüpfung „_ZOOM“ neu gestartet werden – so ist die Vergrößerung von höherer Qualität.
Palette change, P: Umschalten zwischen drei Farbpaletten für Filter – muss generell dem Filter in der Filterschublade entsprechen!
- „UV/IR“ – entspricht etwa den natürlichen Farben.
- „DualBand“ – entspricht etwa HHO-Palette, damit wird H-alpha als orange und O-III als tiefblau angezeigt, und die Details sind besser sichtbar.
- „UHC“ – entspricht etwa den natürlichen Farben, soweit es mit dem UHC-Lichtverschmutzung Filter möglich ist.

Background correction, B: Aktivierung/Deaktivierung der zusätzlichen Hintergrundkorrektur, falls der Hintergrund fleckig erscheint (besonders am Rand). Die Funktion arbeitet nur dann richtig, wenn das Objekt kleiner als das Sichtfeld ist.

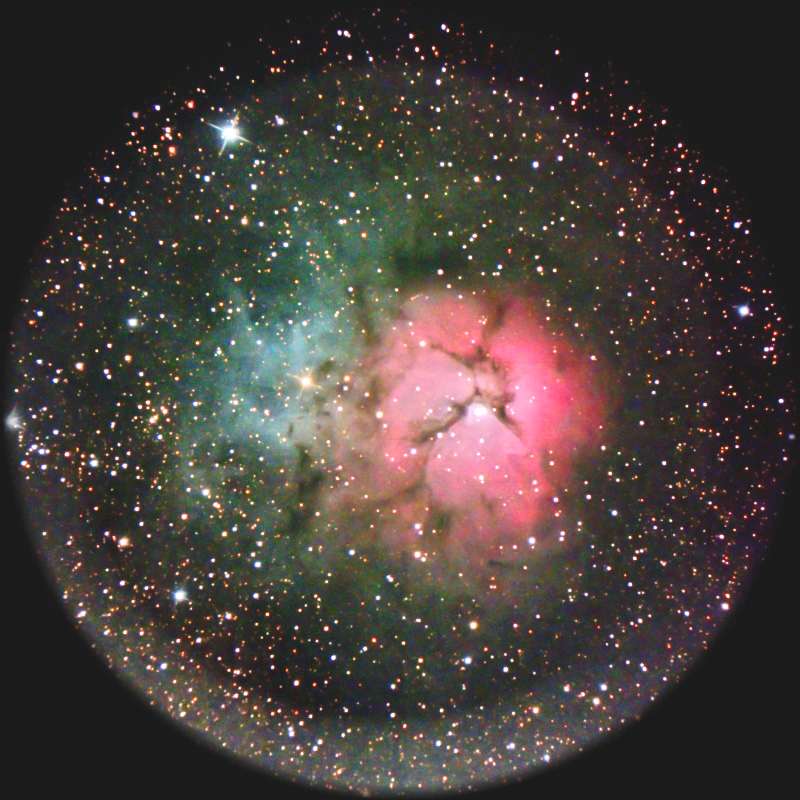
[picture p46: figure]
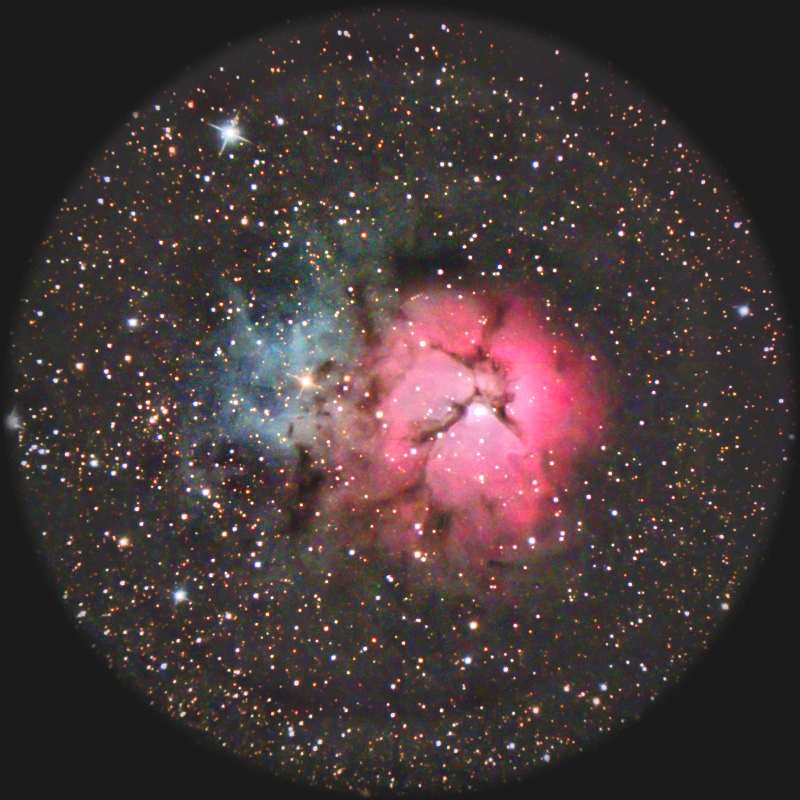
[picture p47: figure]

Statusleiste unten am Fenster zeigt, welcher Modus aktiv ist (Echtzeit/Stacking), welche Farbpalette aktiv ist und ob Hintergrundkorrektur aktiv ist.

Ablauf

1. Am besten in „Park“ Position: Okular an das Teleskop montieren und alle Kabel anschließen. Wenn der Rechner eingeschaltet ist, sieht man im Okular das Hintergrundbild mit dem Text „Robert-Mayer-Sternwarte“.
2. DigitalEyepieceAPP Software starten. Auf dem PC und im Okular soll ein Bild mit Rauschen oder ein überbelichtetes Bild zu sehen sein, oder ein Echtzeitbild mit Sternen, wenn das Teleskop nach oben zeigt.
3. Montierung in „Unpark“ Position bringen und Sternfeld anfahren.

### 4. Fokussieren erfolgt im Echtzeitmodus mit aktiviertem Zoom. Dabei werden vergrößerte

Ausschnitte aus dem Bild angezeigt, aus der Mitte und aus vier Randbereichen. Eine Besonderheit des eingesetzten Reducers ist, dass die Sterne am Rand nur dann rund sind, wenn der optimale Fokuspunkt erreicht ist. Demgemäß orientiert man sich beim Fokussieren auf die Form und Größe von Sternen. Fokussieren erfolgt wie gewohnt mit der Fernbedienung des motorisierten Fokussierers.

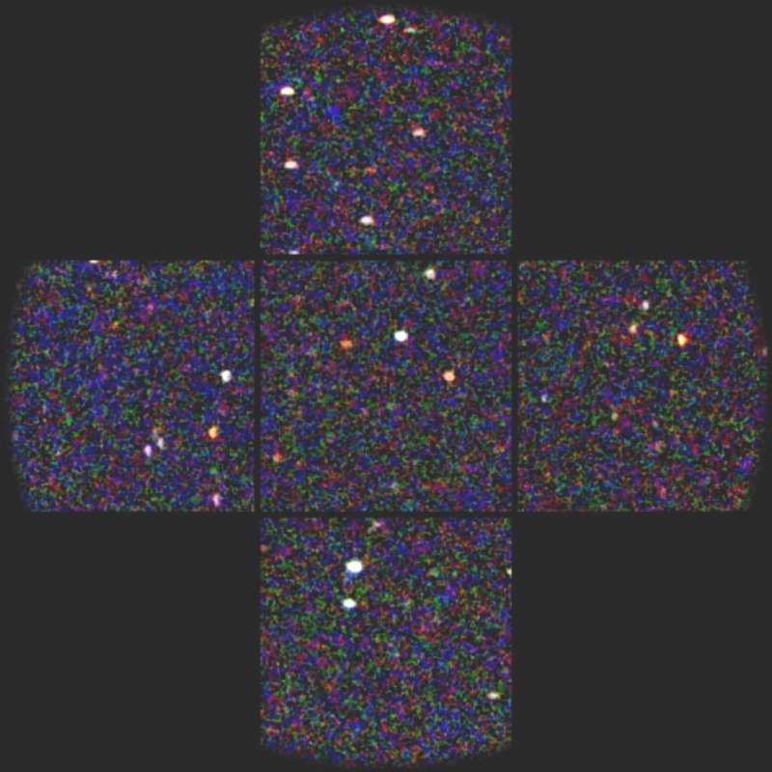
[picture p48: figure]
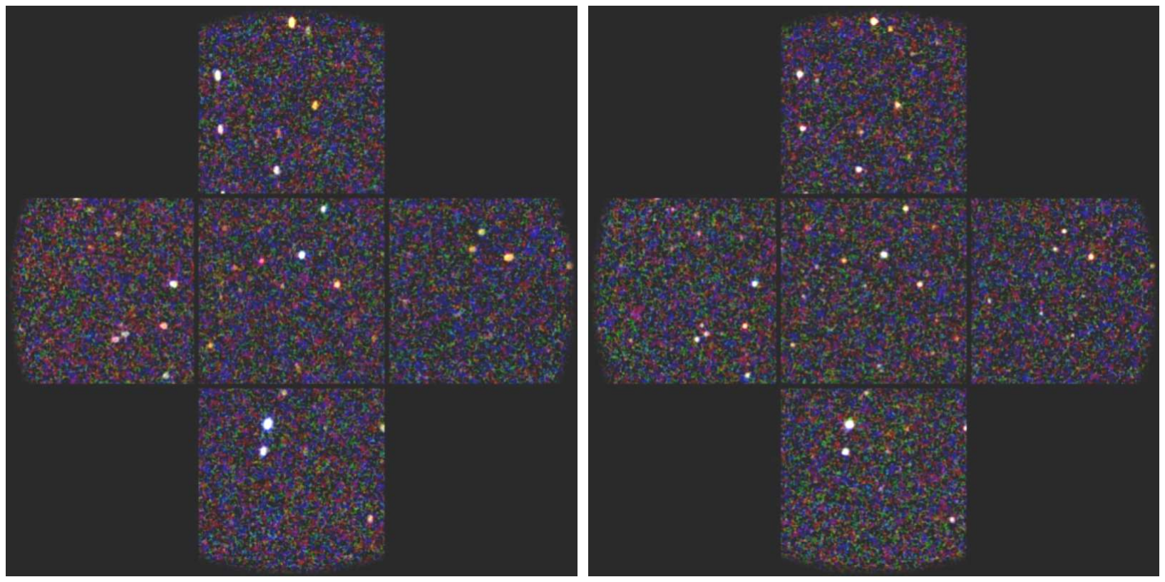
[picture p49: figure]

5. Alternativ kann mit Bahtinov-Maske fokussiert werden. Bahtinov-Maske vorne auf das Teleskop setzen. Einen hellen Stern aufsuchen und im Okular zentrieren. Mit der Fernbedienung am Teleskop fokussieren, bis das Bild symmetrisch erscheint. Dabei kann optional die Taste „Zoom“ verwendet werden.

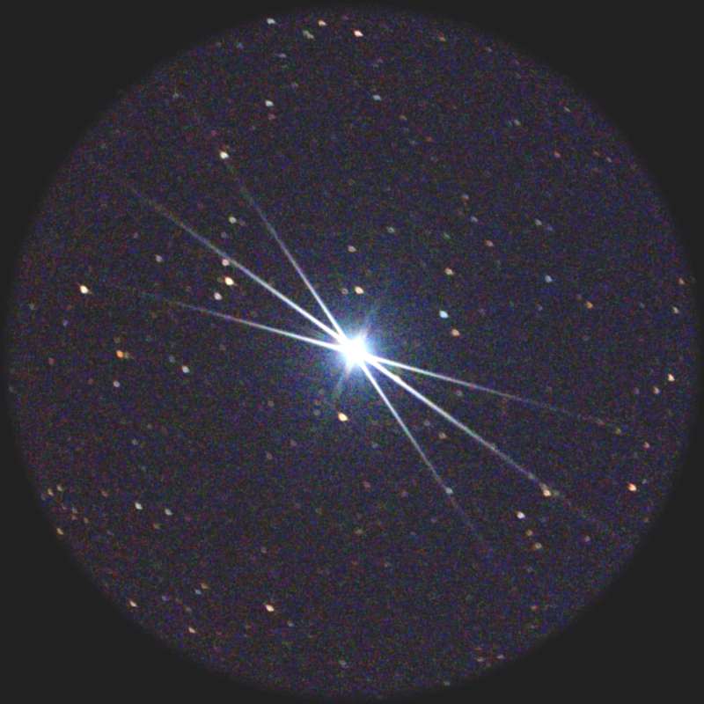
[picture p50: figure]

Dann Bahtinov-Maske entfernen!

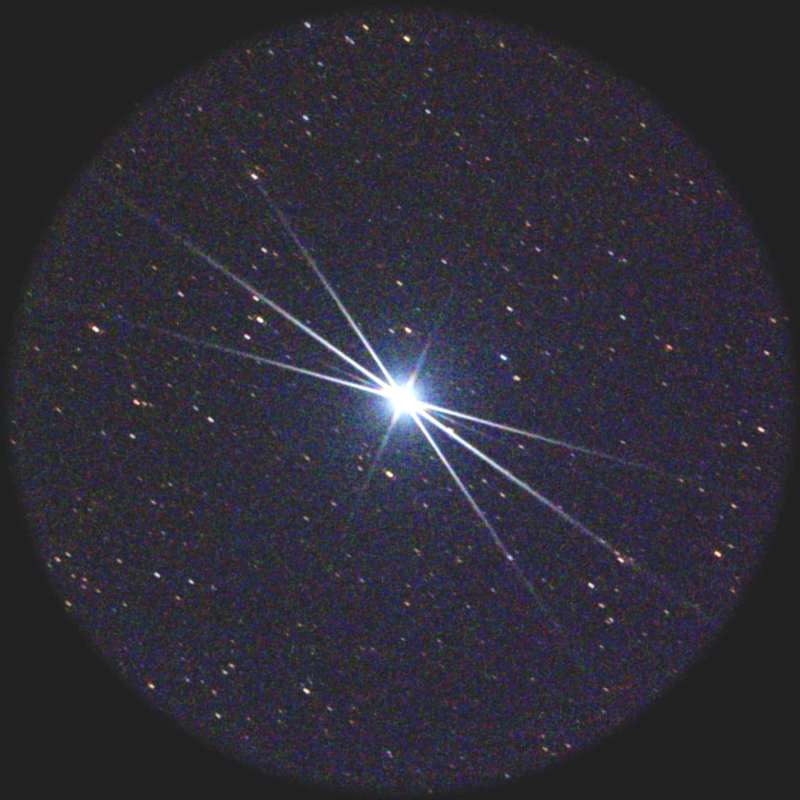
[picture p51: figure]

### 6. Die Fokussierung des Okular-Displays erfolgt über die drehbare Fokussierhülse und kann

individuell für jeden Beobachter eingestellt werden:

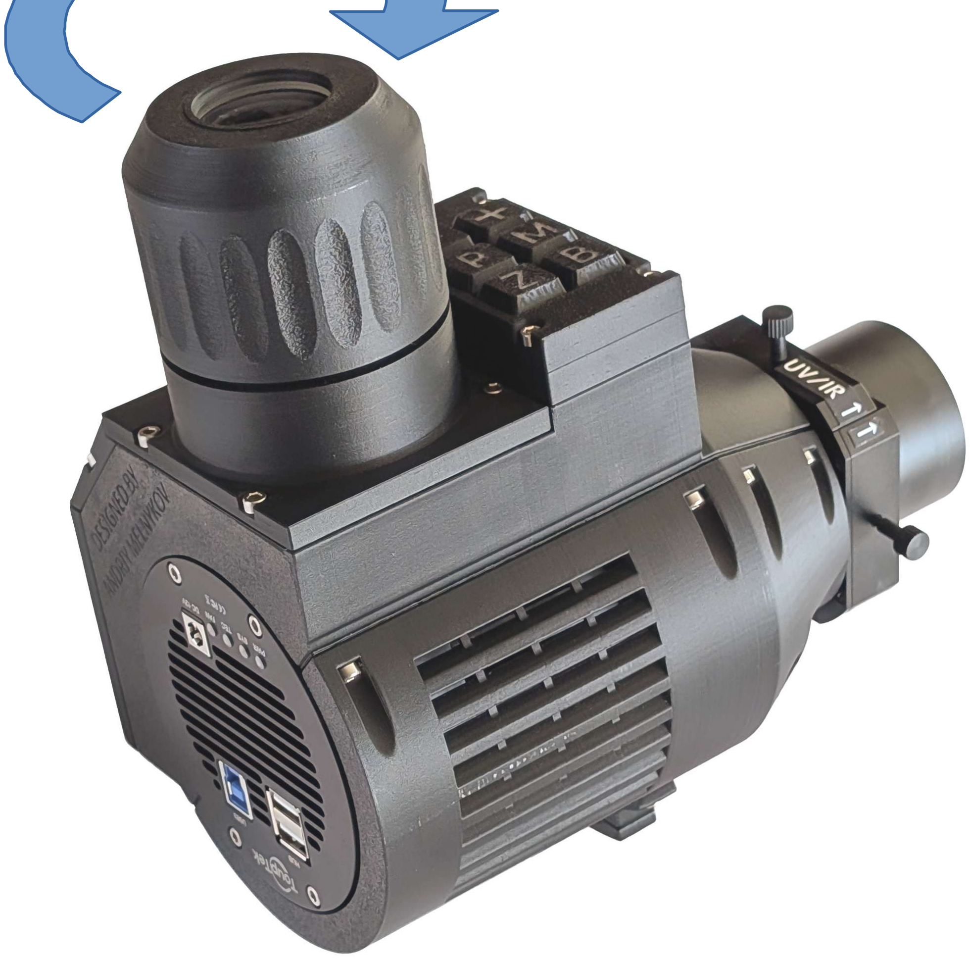
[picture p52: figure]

7. Objekt auswählen und die Montierung anfahren lassen. Das Okular bei Bedarf durch Drehen des Gehäuses an die Beobachtungsposition anpassen (Rändelschrauben nicht lösen!) – dabei auf die Kabel achten. Objekt zentrieren. Stacking-Modus aktivieren.
8. Neues Objekt: Echtzeitmodus aktivieren. Objekt anfahren. Das Okular bei Bedarf drehen. Stacking-Modus aktivieren.
9. Bei der Beobachtung von Emissionsnebeln lohnt es sich, einen Dual-Band oder UHC Filter zu verwenden. Beim Einsetzen des Filters müssen die Pfeilmarkierungen am Filter und am Okular übereinstimmen. Die aktivierte Farbpalette in der Software muss dem eingesetzten Filter entsprechen. Filter werden in der Filterschublade mit einer Fixierschraube gehalten.

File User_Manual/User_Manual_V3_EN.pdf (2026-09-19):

User manual for electronic eyepiece V3, 19.09.2026

The electronic eyepiece is designed for observing deep-sky objects (galaxies, nebulae, globular clusters and stars) with the CDK20 telescope.
The eyepiece is not suitable for observing the Moon or planets and must never be used to observe the Sun!
The electronic eyepiece consists of an astronomy camera, filter drawer, optical reducer (which also serves as a 2-inch barrel), eyepiece display and keypad. The camera, reducer and filter drawer form the permanently assembled optical unit. The outer housing with the display and keypad can rotate around the camera for more comfortable viewing.

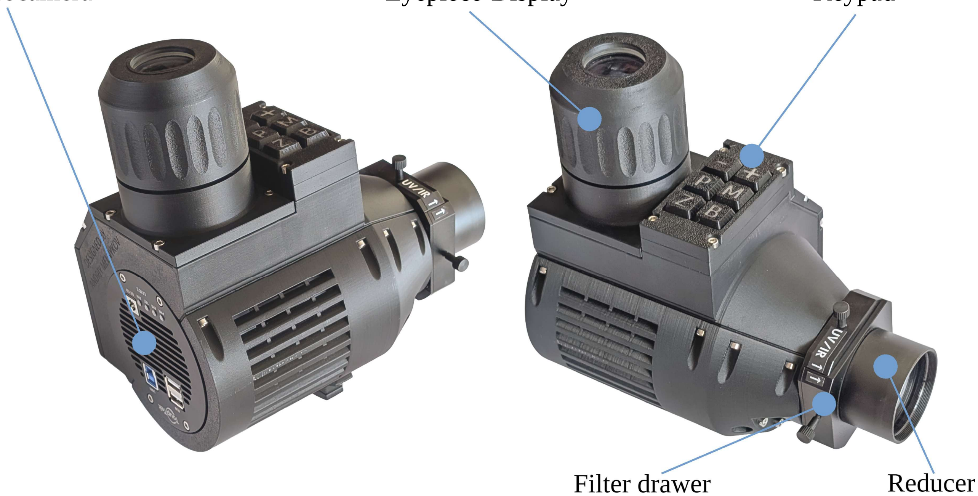
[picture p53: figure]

Mounting

Insert the electronic eyepiece directly into the telescope's 2-inch holder (without a star diagonal) and secure it with the thumbscrews. Check the following:
- The bright alignment marks on the eyepiece and telescope must line up.
- The eyepiece must sit flush and must not be tilted.
Astrocamera | Eyepiece-Display | Keypad

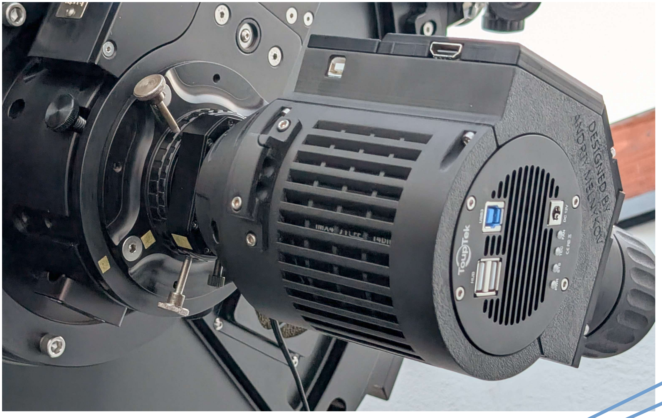
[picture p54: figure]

Alignment marks

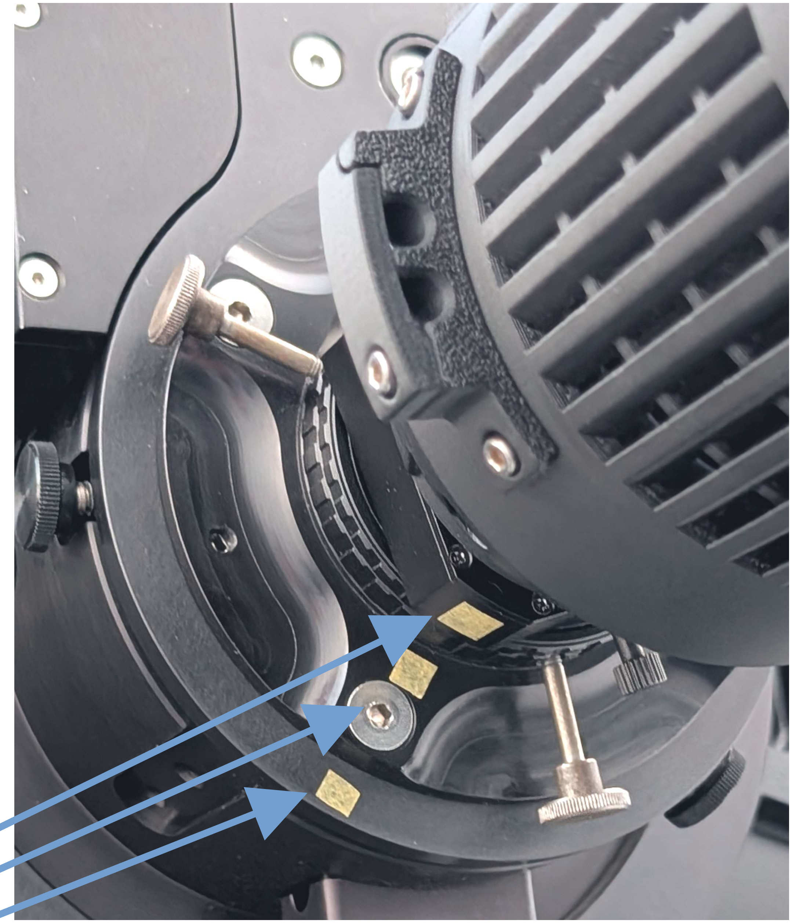
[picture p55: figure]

Connections

The electronic eyepiece requires four cables:

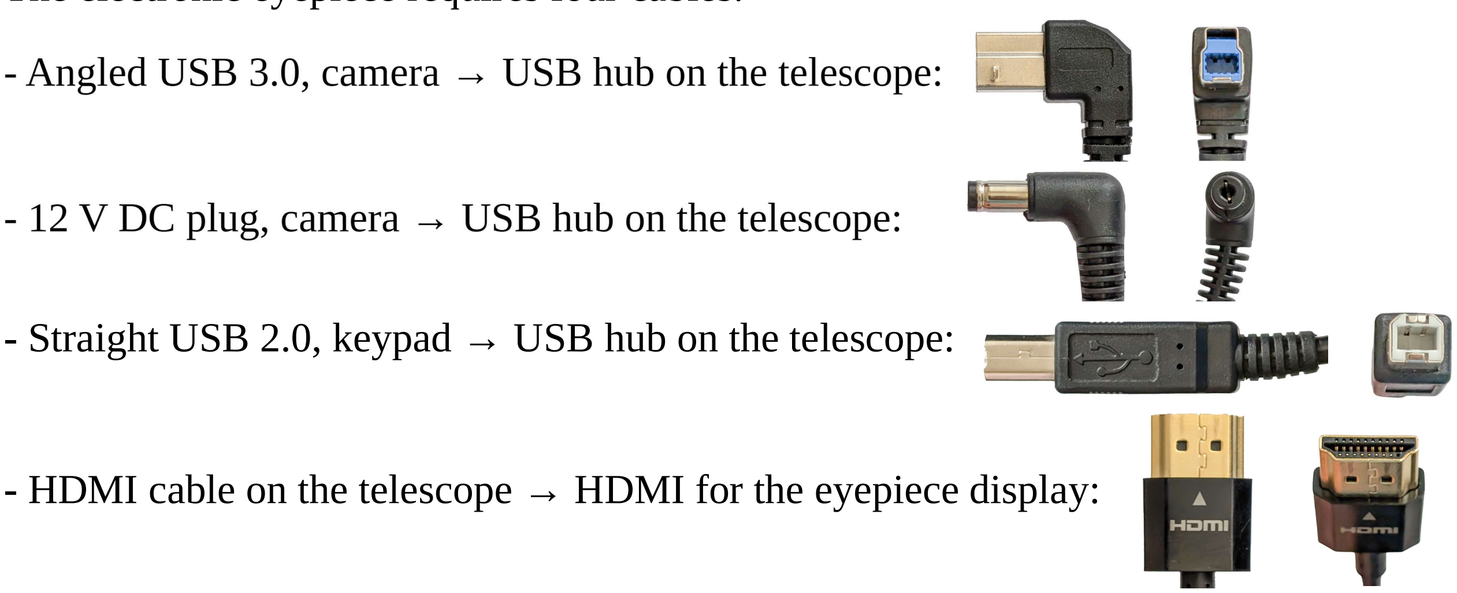
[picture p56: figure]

- Straight USB 2.0, keypad → USB hub on the telescope:
- HDMI cable on the telescope → HDMI for the eyepiece display:


The camera and filter drawer must always remain attached to the telescope in the same position. The housing with the eyepiece display can be rotated around the camera with slight resistance.
The USB keypad and HDMI cables can be secured to the housing to relieve strain on the connectors (these two cables move with the housing when the eyepiece is rotated):

USB2.0, keypad HDMI, display

USB3.0, camera

DC 12V power


Operation

The electronic eyepiece software is located on the computer in the “DigitalEyepieceAPP” folder on the desktop. The folder contains three shortcuts for launching the software with different settings.
- “DigitalEyepieceAPP” starts the software in standard mode with a 0.5° field of view.
- “DigitalEyepieceAPP_ZOOM” starts the software in 2x zoom mode with a 0.25° field of view. This mode is less sensitive than standard mode.
- “DigitalEyepieceAPP_HighSensitivity” starts the software with a 0.5° field of view, higher sensitivity, lower resolution and less aggressive colors for very faint objects.
The software is controlled using a small number of GUI buttons on the PC or, alternatively, using the keypad on the eyepiece. The six buttons on the eyepiece correspond to the six upper GUI buttons in the software.
Images are saved automatically once per minute in the “SW/saved_pictures” folder.
-, + | -, + | Brightness, stretching, bring out details
Palette change | P | Switch color palettes for different filters
Mode change | M | Switch between real-time and stacking modes
Zoom | Z | Magnify the image
Background correction | B | Additional background correction
Save picture | | Save image
Exit | | Exit program


-, +: Adjust the image brightness and how much detail is shown in the deep-sky object. Start with a low setting to reduce visible noise, then increase it as stacking progresses to reveal more detail. There is always a trade-off between noise and detail.
Mode change, M: Switches between real-time and stacking modes. In real-time mode, you can move the telescope to centre the object. In stacking mode, the telescope must remain still and the mount must be tracking.
Zoom, Z: Enables or disables digital magnification, which can improve the view of small objects. It is also used for focusing in real-time mode. For higher-quality magnification, restart the software using the “_ZOOM” shortcut.
Palette change, P: Switches between three color palettes for different filters. The selected palette must match the filter in the filter drawer.
- „UV/IR“ – approximately reproduces natural colors.
- „DualBand“ – approximates the HHO palette, displaying H-alpha as orange and O-III as deep blue so that details are more visible.
- „UHC“ – reproduces natural colors as closely as possible with the UHC light-pollution filter.

Background correction, B: Enables or disables additional background correction if the background appears blotchy, especially near the edge. This function works correctly only when the object is smaller than the field of view.


The status bar at the bottom of the window shows the active mode (real-time or stacking), the active color palette and whether background correction is enabled.

Procedure

1. Preferably with the mount in the “Park” position, attach the eyepiece to the telescope and connect all cables. When the computer is switched on, the eyepiece displays the background image as configured on PC.

### 2. Start the DigitalEyepieceAPP software. The PC and eyepiece should display a noisy or

overexposed image, or a real-time image of stars if the telescope is pointing upwards.
3. Set the mount to the “Unpark” position and slew to a star field.
4. Focus in real-time mode with zoom enabled. The software displays enlarged sections from the centre of the image and from four areas near the edge. A feature of the reducer is that stars at the edge appear round only when the optimum focus has been reached. Use the shape and size of the stars as a focusing guide. Focus as usual with the remote control for the motorised focuser.


5. Alternatively, focus with a Bahtinov mask. Place the Bahtinov mask over the front of the telescope. Slew to a bright star and centre it in the eyepiece. Use the telescope's remote control to focus until the pattern appears symmetrical. The “Zoom” button can be used if desired.


Then remove the Bahtinov mask!


6. Focus the eyepiece display using the rotating focusing sleeve. It can be adjusted for each observer:


7. Select an object and slew the mount to it. If necessary, rotate the housing to place the eyepiece in a comfortable viewing position (do not loosen the thumbscrews). Watch the cables while rotating it. Centre the object and enable stacking mode.
8. To view a new object, enable real-time mode, slew to the object, rotate the eyepiece if necessary and then enable stacking mode.
9. A dual-band or UHC filter is useful when observing emission nebulae. When inserting a filter, align the arrow marks on the filter and eyepiece. The color palette selected in the software must match the installed filter. A retaining screw holds the filter in the filter drawer.

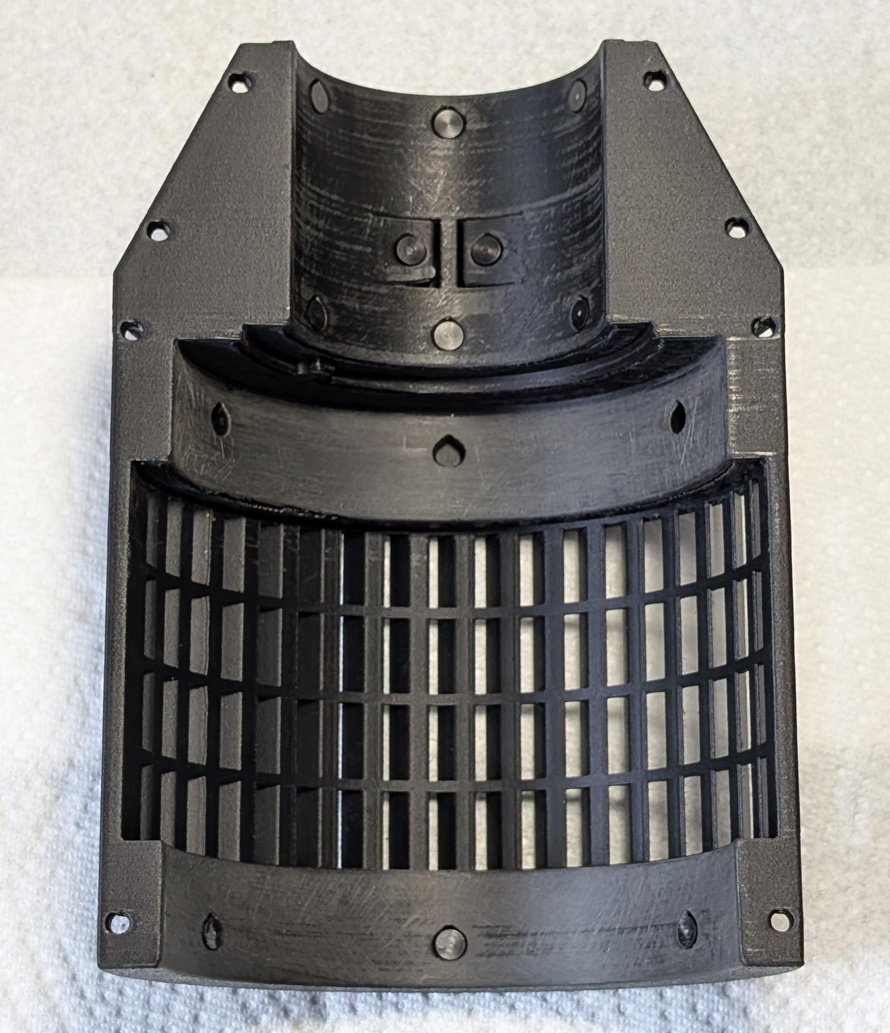
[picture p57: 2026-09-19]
Assembly/15_Assembly.jpg

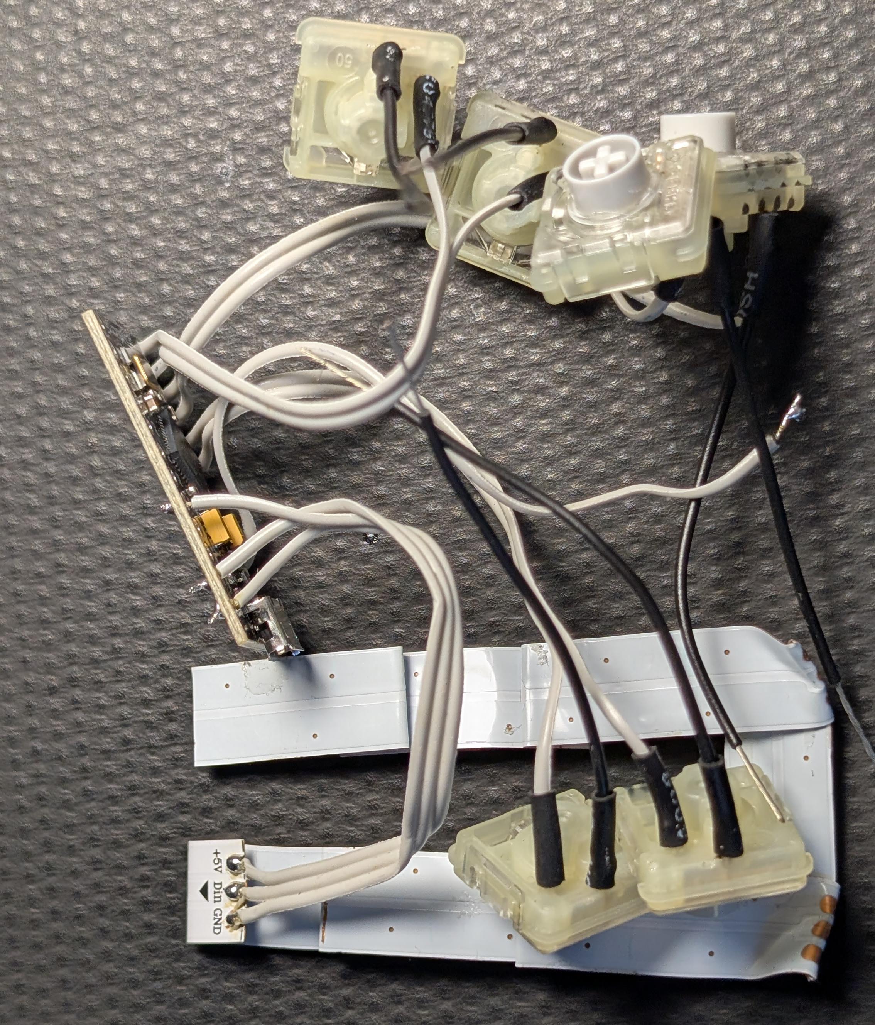
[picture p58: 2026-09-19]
Assembly/29_Assembly.jpg

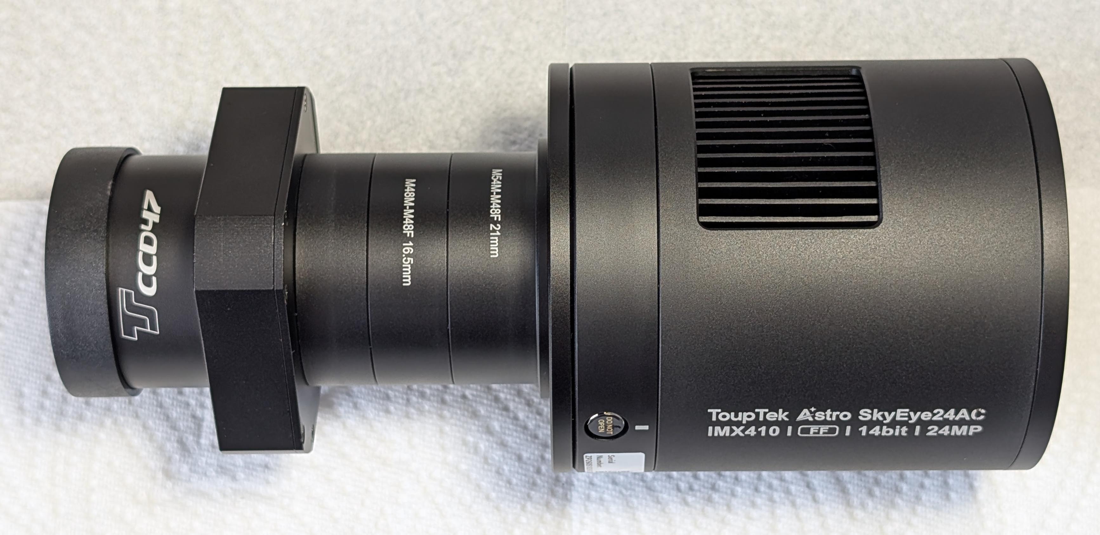
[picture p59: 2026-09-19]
Assembly/13_Assembly.jpg

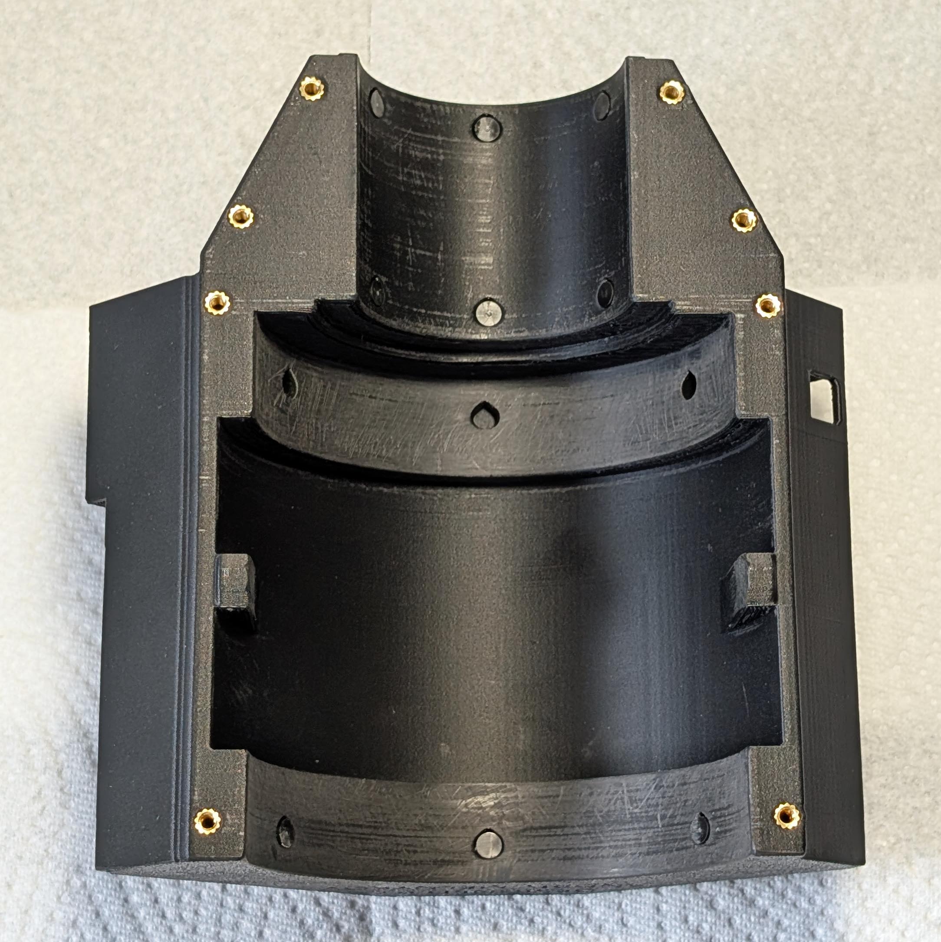
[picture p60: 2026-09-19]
Assembly/14_Assembly.jpg

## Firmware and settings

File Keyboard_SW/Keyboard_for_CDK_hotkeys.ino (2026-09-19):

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

// Arduino board: ProMicro 5V / 16 MHz
// Connections:
//Arduino #9  - key1 -
//Arduino #8  - key2 +
//Arduino #7  - key3 P
//Arduino #6  - key4 M
//Arduino #5  - key5 Z
//Arduino #4  - key6 B
//common for keys - GND

//LED DIO - pin A3
//LED +5V - pin RAW
//LED GND - pin GND

#include <Keyboard.h>
#include <Adafruit_NeoPixel.h>

#define LED_DO    21
#define LED_COUNT  7

Adafruit_NeoPixel strip(LED_COUNT, LED_DO, NEO_GRB + NEO_KHZ800);

// RGB values for each LED as constants
const uint8_t LED1_R = 15;
const uint8_t LED1_G = 1;
const uint8_t LED1_B = 0;

const uint8_t LED2_R = 15;
const uint8_t LED2_G = 1;
const uint8_t LED2_B = 0;

const uint8_t LED3_R = 15;
const uint8_t LED3_G = 1;
const uint8_t LED3_B = 0;

const uint8_t LED4_R = 0;
const uint8_t LED4_G = 0;
const uint8_t LED4_B = 0;

const uint8_t LED5_R = 15;
const uint8_t LED5_G = 1;
const uint8_t LED5_B = 0;

const uint8_t LED6_R = 15;
const uint8_t LED6_G = 1;
const uint8_t LED6_B = 0;

const uint8_t LED7_R = 15;
const uint8_t LED7_G = 1;
const uint8_t LED7_B = 0;


int LED_pin = 17;  // The RX LED has a defined Arduino pin
int key1_pin = 9;
int key2_pin = 8;
int key3_pin = 7;
int key4_pin = 6;
int key5_pin = 5;
int key6_pin = 4;
int cycle_delay = 10;

int key1=1;
int key2=1;
int key3=1;
int key4=1;
int key5=1;
int key6=1;

int key1_old=1;
int key2_old=1;
int key3_old=1;
int key4_old=1;
int key5_old=1;
int key6_old=1;


void sendHotkey(uint8_t key) {
  Keyboard.releaseAll();
  delay(30);

  Keyboard.press(KEY_LEFT_CTRL);
  delay(10);

  Keyboard.press(KEY_LEFT_ALT);
  delay(30);
  
  //Keyboard.press(KEY_LEFT_SHIFT);

  Keyboard.press(key);
  delay(100);
  
  Keyboard.release(key);
  delay(100);

  Keyboard.release(KEY_LEFT_ALT);
  Keyboard.release(KEY_LEFT_CTRL);
  delay(40);        // small gap before next possible hotkey

  Serial.print("Arduino detected button ");
  Serial.println(key + 1);
}


void setup() {
  pinMode(LED_pin, OUTPUT);  // Set RX LED as an output
  digitalWrite(LED_pin, HIGH);

  pinMode(key1_pin, INPUT_PULLUP);
  pinMode(key2_pin, INPUT_PULLUP);
  pinMode(key3_pin, INPUT_PULLUP);
  pinMode(key4_pin, INPUT_PULLUP);
  pinMode(key5_pin, INPUT_PULLUP);
  pinMode(key6_pin, INPUT_PULLUP);

  //Keyboard.begin(KeyboardLayout_de_DE);
  Keyboard.begin();

  strip.begin();
  strip.show(); // Initialize all LEDs to off

  // Set colors for all 7 LEDs
  strip.setPixelColor(0, strip.Color(LED1_R, LED1_G, LED1_B));
  strip.setPixelColor(1, strip.Color(LED2_R, LED2_G, LED2_B));
  strip.setPixelColor(2, strip.Color(LED3_R, LED3_G, LED3_B));
  strip.setPixelColor(3, strip.Color(LED4_R, LED4_G, LED4_B));
  strip.setPixelColor(4, strip.Color(LED5_R, LED5_G, LED5_B));
  strip.setPixelColor(5, strip.Color(LED6_R, LED6_G, LED6_B));
  strip.setPixelColor(6, strip.Color(LED7_R, LED7_G, LED7_B));

  // Send data once after startup
  strip.show();

  Serial.begin(115200);
}

void loop() {
  key1 = digitalRead(key1_pin);
  key2 = digitalRead(key2_pin);
  key3 = digitalRead(key3_pin);
  key4 = digitalRead(key4_pin);
  key5 = digitalRead(key5_pin);
  key6 = digitalRead(key6_pin);
  
  if ((key1 == 0) && (key1_old == 1)) { 
    sendHotkey(KEY_F13);
  }

  if ((key2 == 0) && (key2_old == 1)) { 
    sendHotkey(KEY_F14);
  }

  if ((key3 == 0) && (key3_old == 1)) { 
    sendHotkey(KEY_F15);
  }

  if ((key4 == 0) && (key4_old == 1)) { 
    sendHotkey(KEY_F16);
  }

  if ((key5 == 0) && (key5_old == 1)) { 
    sendHotkey(KEY_F17);
  }

  if ((key6 == 0) && (key6_old == 1)) { 
    sendHotkey(KEY_F18);
  }

  key1_old = key1;
  key2_old = key2;
  key3_old = key3;
  key4_old = key4;
  key5_old = key5;
  key6_old = key6;
  
  delay(cycle_delay);
}

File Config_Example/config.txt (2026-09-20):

SkyEye24AC   //camera name should contain this string
0 // debug output, screen and log file: 0 - none, 1 - active
1 15 // save pictures automatically yes/no: 1/0, after n-th frame
//--------------- Camera and preprocessing Parameters for video mode
400 //exposure time for video mode, ms
3000 //gain for video mode
0  //White balance Red for video mode
0  //White balance Green for video mode //not all cameras use it
0  //White balance Blue for video mode
200 //offset for video mode
0 //high speed mode for video mode, 0 - not active, 1 - active
1 //use dark frame for hot pixel correction, for video mode, 0 - don't use, 1 - use
1 //subtract dark frame from light frame, for video mode, 0 - don't use, 1 - use
1 //use flat frame for video mode, 0 - don't use, 1 - use
0  //banding filter, 0 - disabled, 1 - rows, 2 - columns
100  // banding filter window size, 3..200
1.3  // banding filter threshold, 1.0 .. 2.0
//--------------- Camera and preprocessing Parameters for foto mode
4000 //exposure time for foto mode, ms
1000  //gain for foto mode
0  //White balance Red for foto mode
0  //White balance Green for foto mode //not all cameras use it
0  //White balance Blue for foto mode
200  //offset for foto mode
1 //use dark frame for hot pixel correction, for foto mode, 0 - don't use, 1 - use
0 //find hot pixels without/additional to dark frame
1 //subtract dark frame from light frame, for foto mode, 0 - don't use, 1 - use
1 //use flat frame for foto mode, 0 - don't use, 1 - use
//--------------- Calibration files
Dark_24AC_400ms_g3000.fits  //dark for video mode
Dark_24AC_4s_g1000.fits  //dark for foto mode
Flat_24AC_UVIR_sky.fits  //flat for both video and foto mode
1  // use spline flat correction
0.0 0.7 1.0  //radius points for spline flat correction
1.000 1.000 0.995  //R channel gain value points for spline flat correction
1.000 1.000 0.995  //G channel gain value points for spline flat correction
1.000 1.000 0.995  //B channel gain value points for spline flat correction
//--------------- Parameters for both video and foto mode
0 //monobin for both video and foto mode - only 0 supported for now!
2 //bin for both video and foto mode, 1, 2, ..
2 //bytes per pixel, 1 for RAW8, 2 for RAW16 - only RAW16 supported for now!
90 //bandwidth
30 // sigma for dark frame hot pixel correction, 3.0 .. 7.0
0  // ROI zoom activation, 0/1: off/on
1500 1  // internal image for processing: scale down to height (pixels), crop to square (0/1 on/off)
0.1 0.07  //blackpoint correction for monitor, x1, y1 of corner point (no correction for x1=y1)
0.1 0.07  //blackpoint correction for eyepiece, x1, y1 of corner point (no correction for x1=y1)
//--------------- Other parameters
25 //cooler target temperature, °C
1 //cooler activation, 0 for cooler off, 1 for cooler on
700  //display size, display window height in pixels
0  //image flip horizontally: 0 - none, 1 - flip
0 //image rotation for display: 0, 1, 2, 3 (0, 90°, 180°, 270° clockwise)
2 //background subtraction: 0 - none, 1 - constant level, 2 - gradient
0.05 0.01 //normalised histogram level from left, for background subtraction, for video and foto mode
0.01 //blackpoint offset, added after background subtraction
1  //circular mask as area for background subtraction (for small image circle): 0 - none, 1 - active
0.8 //circular mask for background subtraction diameter, parts of image height
0  //show circular mask for background subtraction for test: 0 - none, 1 - active
1 //noise reduction, for both video and foto mode: 0 - none, 1 - bilateral filtering
0.2 0.0  //noise reduction strength for video and foto mode, 0..1
30 0.2 0.5  // midtone contrast enhancement for foto mode, detail radius, midtone width, strength, deactivated if strength=0
2.0 0.0  // sharpen enhancement, sigma (size), amount, deactivated if amount=0
1 //circular mask for display (optic like): 0 - none, 1 - active for both video and foto mode
100.0 //initial stretching factor: 1.0 is neutral, higher value is more stretching
0.9 0.85 //star protection factor for stretching, 1 - no effect, 0.5-0.99 - stars are more linear, nebulas darker (for nebula, for stars)
Palette: UV/IR
0.5  //mix between rgb stretch (0.0) and luminance chroma preserving stretch (1.0)
1.18 1.0 1.68  // White balance correction
 1.25 -0.16 -0.09  // R = a*R + b*G + c*B color correction matrix
-0.20  1.35 -0.16  // G = a*R + b*G + c*B
-0.01 -0.27  1.28  // B = a*R + b*G + c*B
Palette: DualBand
0.3  //mix between rgb stretch (0.0) and luminance chroma preserving stretch (1.0)
1.0 1.0 1.0  // White balance correction
 1.0  0.0 0.0   // R = a*R + b*G + c*B color correction matrix
 0.6  0.1 0.0   // G = a*R + b*G + c*B
-0.15 1.2 0.3   // B = a*R + b*G + c*B
Palette: UHC
0.5  //mix between rgb stretch (0.0) and luminance chroma preserving stretch (1.0)
0.92 1.0 1.18  // White balance correction
 1.13 -0.09 -0.04  // R = a*R + b*G + c*B color correction matrix
-0.06  1.33 -0.26  // G = a*R + b*G + c*B
-0.04 -0.40  1.44  // B = a*R + b*G + c*B
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

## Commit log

2026-09-19 assembly first commit
2026-09-20 config example first commit
    [config.txt, config_HighSens.txt, config_ROIzoom.txt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]
2026-09-20 3d models first
    [Cable_Holder.step, Cover_HDMI.step, Eyepiece_Body_Layer0_1_RandomSeam.step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]

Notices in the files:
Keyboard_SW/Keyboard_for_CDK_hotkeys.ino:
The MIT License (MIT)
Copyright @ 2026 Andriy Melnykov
